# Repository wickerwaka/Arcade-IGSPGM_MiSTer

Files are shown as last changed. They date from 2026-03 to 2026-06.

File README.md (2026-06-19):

# This repository now lives in the [MiSTer organization](https://github.com/mister-devel/Arcade-IGSPGM_MiSTer)

# IGS PolyGame Master MiSTer FPGA core

The PolyGame Master (PGM) is an arcade system board released in 1997 by IGS. It has a lot of similarities to SNK's Neo Geo - cartridge based with multiple buses, heavily sprite focused graphics hardware, 68000 main CPU, Z80 for audio.

- Main processor: Motorola 68000 @ 20 MHz
- Sound processor: Zilog Z80 @ 8.4 MHz
- Sound chip: Wavefront ICS2115
- Graphics chip: IGS023

Games come with several flavors of protection hardware on the cartridge. Most feature an ARM7 CPU and in later games the ARM takes on a larger portion of the game update processing.

## Status
This core is currently BETA. Most games work, but the core needs more testing. The PGM platform features a large amount of variants and bootlegs that all require testing. If you encounter issues please report them via github. Save state files can be especially useful for tracking down and reproducing issues, so if you have some then please include them.

## Core Features
- Save States. The core supports save states for all games. It is expected that you can save and restore a save state at any point. If you encounter issues restoring save states, please report them.
- H-Scale. The PGM video signal tends to be squashed horizontally by consumer CRTs. In the Video Settings menu there is an H-Scale option that can be enabled which allows you to scale the width of the image up and down. This only works for analog video and does not play well with the HDMI scaler.
- NVRAM. The 128KB of main RAM on the PGM is battery backed. On the original system this is often used for bookkeeping data such as earning per game. Some games (CAVE shooters) use it for storing per-game settings. It might also be used for high score saving by some games.
- RTC. The PGM also has a battery backed clock. As far as I know this is not used by any games, but it does get displayed at startup by the BIOS. The timer can be adjusted in the BIOS, but at startup it will always be set to the MiSTers current system time.

## Supported games

- Oriental Legend
- Oriental Legend Super
- Dragon World 3
- Dragon World 3 EX
- Dragon World 2001
- The Killing Blade
- The Killing Blade Plus
- Photo Y2K
- Knights of Valour Super Heroes
- Knights of Valour 2
- Martial Masters
- Demon Front
- The Gladiator
- S.V.G. - Spectral vs Generation
- DoDonPachi II - Bee Storm
- DoDonPachi III / Dai-Ou-Jou
- Ketsui: Kizuna Jigoku Tachi
- Espgaluda

## Not yet working

- Knights of Valour
- Knights of Valour Plus
- Knights of Valour 2 Plus - Nine Dragons
- Dragon World Pretty Chance
- Happy 6-in-1

## Sources
Multiple different sources have been used as reference when developing this core.

[MAME](https://www.mamedev.org/) - Tons of information about the PGM system and especially its protection mechanisms. Also used as the source for the initial ICS2115 implementation.

[igspgm.com](https://igspgm.com/) - Motherboard images, cartridge images, archived documents. Super valuable archive of information that could easily have been lost to history.

[PGMTech](https://github.com/laoo/PGMTech) - Solid documentation of PGM memory maps and system architecture

[GUS GF1 Decap](https://github.com/nukeykt/LPC-GUS) - Coming from the same hardware lineage, the GF1 source was a useful reference for how things might be done inside the ICS2115

[Game Bub](https://github.com/elipsitz/gamebub) - ARM7TDMI implementation

## Special Thanks
Thanks to [James](https://www.retrohq.co.uk/) for all the additional insights he was able to provide. The stars aligned and we ended up exploring parts of the system as the same time. I hope I was able to help him half as much as he helped me.

Thanks to [Tim](https://igspgm.com/) for keeping valuable sources of PGM information alive on the internet over the years. It has been an invaluable source of information.

laoo, Xolod, augitesoul and everyone who has playtested, provided feedback and/or support.

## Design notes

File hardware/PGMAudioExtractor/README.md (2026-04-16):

# PGMAudioExtractor

PGMAudioExtractor is RP2350/Pico 2 firmware for capturing the PGM arcade board's external stereo serial audio stream at its **native sample rate** and exporting it over USB CDC as timestamped binary packets.

The host-side capture tool reconstructs the stream into:
- a `.wav` file for listening
- a `.jsonl` metadata sidecar for integrity and timing analysis

This project no longer uses USB Audio Class for primary capture. The current design is aimed at **faithful native-rate extraction** rather than presenting as a standard microphone.

## Current status

Implemented:
- PIO + DMA capture from `CLK`, `LRCLK`, and `SI`
- runtime LRCLK measurement
- native-rate CDC packet transport
- packet metadata with block sequence, frame index, timestamps, and measured LRCLK
- host-side Python capture tool
- picotool-compatible reset/load workflow
- correct capture of both silence and active audio on macOS

See [TODO.md](TODO.md) for remaining cleanup and validation work.

## Audio format assumptions

Current input assumptions:
- externally clocked serial audio
- signals: `CLK`, `LRCLK`, `SI`
- stereo
- signed 16-bit PCM
- 2's complement
- MSB first
- backward-justified / I2S-like timing
- native source rates currently observed around `33074 Hz`, with `44100 Hz` also expected

## USB interface model

The firmware currently enumerates as:
- CDC serial interface carrying the binary capture stream
- reset/vendor interface for `picotool` reboot workflows

There is no UAC streaming path in the current extractor design.

## Build

```sh
make
```

Useful targets:

```sh
make                 # build UF2
make build           # configure + build
make info            # query device info
make load            # build and flash UF2
make bootsel         # reboot device into BOOTSEL mode
make app             # reboot device into application mode
make monitor         # open a serial monitor using screen
make capture         # run Python capture tool (default /tmp/pgm_capture.wav)
make clean           # remove build directory
```

Examples:

```sh
make load
make capture
make capture OUT=/tmp/pgm.wav DURATION=20
make PORT=/dev/cu.usbmodem1101 monitor
```

Defaults can be overridden:

```sh
make PICO_BOARD=pico2
make UF2=build/pgm_audio_extractor.uf2 load
make PORT=/dev/cu.usbmodem1234561 monitor
```

## Capture workflow

Typical workflow:

```sh
make load
make capture OUT=/tmp/pgm_capture.wav DURATION=10
```

This produces:
- `/tmp/pgm_capture.wav`
- `/tmp/pgm_capture.wav.jsonl`
- `/tmp/pgm_capture.wav.raw`

The `.jsonl` file contains one JSON record per received packet with header fields and decoded status payloads.

## Packet protocol

The CDC stream is framed as binary packets with a fixed header followed by a payload.

See [PROTOCOL.md](PROTOCOL.md) for the packet layout and field definitions.

## Resilience behavior

The firmware is designed to tolerate:
- no audio source connected
- no valid LRCLK edges
- no host attached to CDC
- host attached but not actively reading

When no source is present, the device continues running and emits status packets when possible.
When the host is not connected or not draining the CDC stream, packets are dropped instead of blocking capture.

## File layout

- `CMakeLists.txt` - project build setup
- `Makefile` - build, flash, and host capture helpers
- `PROTOCOL.md` - CDC packet protocol documentation
- `src/main.c` - top-level init and main loop
- `src/tusb_config.h` - TinyUSB configuration
- `src/usb_descriptors.[ch]` - USB CDC + reset descriptors
- `src/serial_audio_capture.[ch]` - PIO/DMA capture and packet emission
- `src/serial_audio_capture.pio` - PIO program source
- `src/capture_stream.[ch]` - CDC packet queueing/transport
- `src/rate_measure.[ch]` - LRCLK measurement logic
- `src/ring_buffer.[ch]` - shared stereo frame type / helper ring buffer
- `../../utils/capture_stream.py` - host-side capture/decode tool for both hardware CDC streams and simulator binary packet captures
- `tools/serial_monitor.py` - reconnecting serial monitor helper

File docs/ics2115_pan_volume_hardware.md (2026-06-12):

# ICS2115 hardware pan/volume measurements

`pan_vol_test.csv` records one-voice output for a constant input sample of
`-32768`.  The swept fields are:

- `pan`: `0x00..0xf0` in steps of `0x10`
- `vol_acc`: `0x0000..0xfff0` in steps of `0x10`
- `left`, `right`: captured output samples

The measurements imply that the mixer computes a 12-bit volume index from
`vol_acc >> 4`, subtracts a pan attenuation from that index, converts the result
through a 4096-entry exponential volume table, and then multiplies the sample by
that table value.

## Exact measured function

This Python code reproduces every row of `pan_vol_test.csv` exactly:

```py
import csv

PAN_ATTEN = [
    4096, 508, 364, 304,
    248, 200, 168, 140,
    116, 96, 76, 56,
    40, 28, 12, 0,
]

def volume_lut(i):
    if i <= 0:
        return 0
    if i > 4095:
        i = 4095

    exp = i >> 8
    mant = i & 0xff

    if exp == 0:
        return mant >> 7

    return (((0x100 | mant) << (exp - 1)) + 0xff) >> 8

def f(sample, pan, volume):
    vol_index = volume >> 4
    pan_index = pan >> 4

    left_atten = PAN_ATTEN[15 - pan_index]
    right_atten = PAN_ATTEN[pan_index]

    left_gain = volume_lut(vol_index - left_atten)
    right_gain = volume_lut(vol_index - right_atten)

    left = (sample * left_gain) >> 15
    right = (sample * right_gain) >> 15
    return left, right

bad = []
with open('pan_vol_test.csv', newline='') as fh:
    for row in csv.DictReader(fh):
        pan = int(row['pan'])
        volume = int(row['vol_acc'])
        expected = (int(row['left']), int(row['right']))
        got = f(-32768, pan, volume)
        if got != expected:
            bad.append((pan, volume, expected, got))

print(len(bad))  # 0
```

For `sample == -32768`, the final multiply simplifies to `-gain` because:

```py
(-32768 * gain) >> 15 == -gain
```

## Volume table

The measured table is close to the old MAME/HDL patent-derived table, but it
rounds upward for non-zero fractional entries.

Measured table:

```py
def volume_lut(i):
    if i <= 0:
        return 0
    exp = i >> 8
    mant = i & 0xff
    if exp == 0:
        return mant >> 7
    return (((0x100 | mant) << (exp - 1)) + 0xff) >> 8
```

Equivalent interpretation for `exp > 0`:

```py
ceil(((0x100 | mant) << exp) / 512)
```

The `exp == 0` case must be special-cased; otherwise `exp - 1` is `-1`, which
would be an invalid negative shift in Python and undefined/impossible in C/HDL.

Examples:

```text
index  old MAME/HDL  measured
128    0             1
255    0             1
256    1             1
257    1             2
511    1             2
4095   32704         32704
```

## Pan table

The old MAME/HDL table used:

```text
panlaw[0] = 0xfff
panlaw[i] = 16 - floor(log2(i))
```

The hardware measurements instead match a 16-step attenuation table indexed by
`pan >> 4`:

```py
PAN_ATTEN = [
    4096, 508, 364, 304,
    248, 200, 168, 140,
    116, 96, 76, 56,
    40, 28, 12, 0,
]
```

The HDL stores attenuation in 12 bits, so the first entry is represented as
`0xfff`.  For the measured 12-bit volume index range, `4096` and `4095` both
fully mute because the post-pan index is `<= 0`.

Stereo uses the table symmetrically:

```py
left_atten = PAN_ATTEN[15 - (pan >> 4)]
right_atten = PAN_ATTEN[pan >> 4]
```

Only pan values in steps of `0x10` were measured in this CSV.  The HDL and MAME
now map all values with the same high nibble to the same attenuation, matching
what the measured function does for the swept values.

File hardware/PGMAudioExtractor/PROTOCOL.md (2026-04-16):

# CDC Capture Protocol

PGMAudioExtractor streams native-rate audio over USB CDC as binary packets.

All fields are little-endian.

## Packet framing

Each packet is:
- a fixed header
- followed immediately by `payload_bytes` bytes of payload

Header C definition:

```c
typedef struct __attribute__((packed)) {
    uint32_t magic;        // 'PGMA' = 0x414D4750
    uint16_t version;      // currently 1
    uint16_t type;         // 1 = audio, 2 = status
    uint32_t payload_bytes;
    uint32_t block_seq;
    uint64_t frame_start;
    uint32_t frame_count;
    uint64_t t_us;
    uint32_t raw_lrclk_hz;
    uint32_t flags;
} pgm_capture_packet_header_t;
```

## Common header fields

- `magic`: sync word used to recover framing
- `version`: protocol version
- `type`: payload type
- `payload_bytes`: number of bytes after the header
- `block_seq`: monotonically increasing packet/block sequence number
- `frame_start`: first stereo frame index represented by this packet
- `frame_count`: number of stereo frames represented by this packet
- `t_us`: `time_us_64()` timestamp captured on-device when the packet/block was emitted
- `raw_lrclk_hz`: current unsnapped measured LRCLK rate in Hz, or `0` when unavailable
- `flags`: status bitfield

## Packet types

### Type 1: audio block

Payload is raw interleaved stereo PCM frames:

```c
typedef struct {
    int16_t left;
    int16_t right;
} stereo_frame_t;
```

For audio packets:
- `payload_bytes = frame_count * 4`
- `frame_start` and `frame_count` define the exact sample range in the capture timeline

### Type 2: status

Payload C definition:

```c
typedef struct __attribute__((packed)) {
    uint32_t uptime_ms;
    uint32_t rate_hz;
    uint32_t raw_rate_hz;
    uint32_t edge_count;
    uint32_t elapsed_us;
    uint32_t idle_us;
    uint32_t rate_status;
    uint32_t ready_mask;
    uint32_t processed_dma_blocks;
    uint32_t dropped_dma_blocks;
    uint32_t dropped_audio_frames;
    uint32_t channel_word_count;
    uint32_t stereo_frame_count;
    uint32_t nonzero_sample_count;
    int16_t last_left_sample;
    int16_t last_right_sample;
    uint32_t stream_dropped_packets;
    uint32_t stream_dropped_bytes;
    uint32_t stream_queue_depth;
    uint32_t reserved;
} pgm_capture_status_payload_t;
```

Status packets provide periodic health/diagnostic information and do not contribute audio samples.

## Flags

Current flag definitions:

- `1 << 0` `PGM_CAPTURE_FLAG_RATE_VALID`
- `1 << 1` `PGM_CAPTURE_FLAG_CAPTURE_RUNNING`
- `1 << 2` `PGM_CAPTURE_FLAG_DMA_DROP`
- `1 << 3` `PGM_CAPTURE_FLAG_AUDIO_DROP`
- `1 << 4` `PGM_CAPTURE_FLAG_QUEUE_DROP`
- `1 << 5` `PGM_CAPTURE_FLAG_NO_HOST`

## Timeline model

The primary timing model is:
- sample values from audio payloads
- monotonically increasing `frame_start` / `frame_count`

`t_us` is an anchor timestamp for block emission, not a per-sample timestamp.

## Integrity checking

The host should verify:
- `block_seq` continuity
- `frame_start` continuity across audio packets
- absence of diagnostic drop flags when lossless capture is desired

The provided `utils/capture_stream.py` receiver records packet metadata to JSONL and summarizes packet/frame gaps at the end of capture. It can read either the live CDC stream from the capture hardware or a simulator-produced binary packet file.

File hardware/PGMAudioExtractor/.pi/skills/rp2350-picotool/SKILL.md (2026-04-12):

---
name: rp2350-picotool
description: "Use picotool to talk to the RP2350 device, check boot mode, query info, reboot between BOOTSEL and APPLICATION, and load UF2 firmware."
---

Use this skill whenever working with the RP2350-based device attached to this project.

## Device modes

The device has two important modes:

- `BOOTSEL` mode
  - firmware can be loaded
  - `picotool info` should work
  - `picotool load <file.uf2>` should work
- `APPLICATION` mode
  - normal firmware execution mode

## Mode switching

Reboot the device into `BOOTSEL` mode with:

```bash
picotool reboot -u -F
```

Reboot the device into `APPLICATION` mode with:

```bash
picotool reboot -a -F
```

Notes:
- `-F` forces the operation without interactive confirmation.
- The current firmware exposes the Pico USB reset interface, so `picotool reboot -u -F` should work from `APPLICATION` mode.
- After a mode switch, allow a short delay and retry once if `picotool info` or `picotool load` races device re-enumeration.
- If `picotool reboot -u -F` fails to put the device into `BOOTSEL` mode, the device may be in a bad state.
- In that case, stop and prompt the user with exactly:

```text
BOOTSEL PLZ?!
```

The user will then manually place the device into `BOOTSEL` mode.

## BOOTSEL-only commands

These commands require the device to already be in `BOOTSEL` mode and will error otherwise:

```bash
picotool info
picotool load <firmware.uf2>
```

`picotool load <firmware.uf2>` reboots the device into `APPLICATION` mode when the load completes successfully.

## Recommended workflows

### Check device status / inspect firmware

1. Try to enter `BOOTSEL` mode:

```bash
picotool reboot -u -F
```

2. Query device info:

```bash
picotool info
```

If `picotool info` fails immediately after rebooting into `BOOTSEL`, wait briefly and retry once.

3. If step 1 fails or step 2 indicates the device is not in `BOOTSEL`, ask the user:

```text
BOOTSEL PLZ?!
```

4. After the user intervenes, retry:

```bash
picotool info
```

### Load new firmware

1. Put device in `BOOTSEL` mode:

```bash
picotool reboot -u -F
```

2. Load firmware:

```bash
picotool load <path-to-firmware.uf2>
```

If `picotool load` fails immediately after entering `BOOTSEL`, wait briefly and retry once.

3. If entering `BOOTSEL` fails, ask the user exactly:

```text
BOOTSEL PLZ?!
```

Then retry the load.

## Operational guidance

- Prefer `picotool info` to confirm the device is reachable in `BOOTSEL` mode before loading firmware.
- Do not assume `picotool load` can succeed from `APPLICATION` mode.
- A successful `picotool load` returns the device to `APPLICATION` mode automatically, so no extra reboot command is needed afterward.
- If a BOOTSEL transition just occurred, allow a short re-enumeration delay before deciding the command failed.
- When reporting status, mention which mode the device is believed to be in.
- Include the exact `picotool` command used when summarizing actions.

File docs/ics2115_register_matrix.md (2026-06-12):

# ICS2115 Register Behavior Matrix

Tracking document for validating the ICS2115 RTL (`rtl/ics2115/`) against real
hardware. Every known register access from firmware evidence gets one or more
**behavior rows**; each row carries a status and a test ID. The goal is to burn
this document down until every row is `TESTED-PASS` or justified `N/A`, with a
test suite that produces identical output on the simulator and real hardware.

Evidence corpora, in order of authority:

1. **PGM Z80 BIOS** decompile — `~/Source/PGM-BIOS/pgm_bios_z80_raw_decompiled.c`
   (access sites enumerated in [`ics2115_access_inventory.csv`](ics2115_access_inventory.csv),
   regenerate/verify with `python3 util/ics_access_inventory.py [--check]`).
2. **Turtle Beach WaveFront firmware** (`OSWF.bin`) — analyzed in
   `~/Source/PGM-BIOS/ICS2115_OSCILLATOR_REGISTERS.md` (cited below as **TB doc**).
3. **Hardware experiments** — prior captures behind
   `docs/ics2115_pan_volume_hardware.md` and `docs/ics2115_vol_incr_analysis.md`.
4. **MAME** `~/Source/mame/src/devices/sound/ics2115.cpp` — reference only, has
   open TODOs ("Verify interrupt, envelope, timer period / Verify unemulated
   registers", ics2115.cpp:14-15).
5. **GF1 netlist** `~/Source/ICS2115/LPC-GUS/gf1.v` — microarchitecture hints
   from a related chip (timers ~440-487, voice RAM ~73-300); never authority.

## Status legend

```
UNKNOWN       no evidence for what real hardware does
ASSUMED       behavior inferred from firmware usage / references; not modeled or untested
MODELED       RTL implements the assumed behavior; no register-level validation test yet
TEST-DEFINED  test exists, not yet run on both targets
TESTED-SIM    test passes on simulator; hardware run pending
TESTED-PASS   sim and hardware match (and match the assumed behavior)
TESTED-FAIL   sim/hardware diverge, or hardware contradicts the assumption -> RTL fix needed
N/A           unreachable / don't-care (justification required)
```

Burn-down dashboard (run from repo root):

```bash
grep -oE '\| (UNKNOWN|ASSUMED|MODELED|TEST-DEFINED|TESTED-SIM|TESTED-PASS|TESTED-FAIL|N/A) \|' \
    docs/ics2115_register_matrix.md | sort | uniq -c
```

## Test ID index

Tests live in `util/ics_reg_tests/` (T-RB and T-PROBE implemented; runner
`util/run_ics_reg_tests.py --target {sim,hw}`, differ
`util/compare_ics_results.py`). All run through the Z80 driver path on both
targets (`ICS2115Remote` hardware / `open_sim(transport="debug_link")`),
emitting JSONL for a common differ.
**Sim-native (`SimICS2115Remote`) is introspection-only** — it bypasses the
register interface and returns zeroed IRQ counts.

Most rows are **record-only**: the test records what the chip does rather than
asserting an expectation, and adjudication happens when the hardware JSONL is
diffed against the sim baseline. For those rows `TESTED-SIM` means the sim
baseline is captured and deterministic (two consecutive runs diff clean —
verified 2026-06-11, 152/152 records, `results/sim_run1.jsonl` is the baseline
artifact).

The sim debug-link transport is validated (2026-06-11,
`audio_tests/debug_link_bench.py`): ~1 vblank frame of emulated time per
synchronous command (~0.6 s wall; `read_voice` 2 frames), 200/200 mixed
read/write ops clean. In the simulator the byte stream rides a WORK_RAM ring
(`RamComms`, see `docs/ics2115_remote.md`) because `rom_cache` makes the
PicoROM ROM-mailbox incoherent there; the TestROM auto-detects and the 68k/Z80
register path is identical on both targets. Batch requests to amortize the
per-poll frame cost in large sweeps.

| ID | What it does | Infra needed |
|---|---|---|
| T-RB | per-register readback: walking bits, voice-select isolation, byte-width disturbance (does a LOWER8 write touch the upper byte?) | existing protocol |
| T-PROBE | reserved regs 0x13-0x3F, 0x44-0x49, 0x4E: read defaults, write-then-read, full 0x40-0x4F snapshot before/after to catch aliasing, IRQ-count + audio side-effect check | existing protocol |
| T-TMR | timer period vs `((scale&0x1f)+1)*(preset+1) << (4+(scale>>5))`: (preset, scale) grid incl. 0x00/0x1f/shift extremes, measured as IRQs per N vblank frames | I-1 |
| T-IRQ | 0x4A enable-vs-pending, 0x43 read status bits, clear-on-read of 0x40/0x41 (which port widths trigger it?), IRQ line gating with enable=0 | I-1, I-2 |
| T-IRQV | multi-source IRQV ordering/priority, auto-clear granularity (one source or both? low-byte vs high-byte read?), ActiveOsc gating of the scan, idle read value | I-2 |
| T-VOICE | one-shot/loop/bidir end IRQs, vol-ramp IRQ at VEnd, IRQ from a voice above ActiveOsc | I-2 |
| T-OCTL | OscCtl key-on variants 0x10/0x20/0x30 (audio effect?), `shadow|0x02` transient, readback width/value, MAME's timer-start-bit guess (write bit0/1 with timers configured but stopped, watch IRQ counts) | I-1 |
| T-VMODE | 0x12 per-voice vs global scope (write voice A, read voice B), bits 7:2 readback + audio effect | audio capture |
| T-SYS | 0x4D readback + bit-gating side effects + strobe replay; 0x4C write sensitivity; 0x4B vector semantics; reg-select port echo; port-0 status bits | I-1, audio capture |
| T-AUD | OscConf format-bit encoding sweep (TB doc conclusion 4), regression of pan/vol tables | existing capture/compare |

Infra items: **I-1** = frame-counted IRQ measurement (TestROM vblank frame
counter + atomic `{frame_count, irq_counts}` remote command) and **I-2** =
Z80-side IRQ event ring (raw status/IRQV/0x43 bytes per service, 32 entries) —
both implemented 2026-06-11 (driver magic 0x1c52) and validated: measured
timer rate 35 IRQs/20 frames vs 34.9 predicted at 103 Hz.

**Convergence status (2026-06-12)**: after the RTL fix package, 172/178
records match between targets (`results/sim_baseline.jsonl` vs
`results/hw_baseline.jsonl`). The 6 residuals: hardware run-to-run variance
in IRQV round-robin corner cases (multi-pend ordering and ActiveOsc gating
need tests that precondition the round-robin pointer deterministically),
the 0x4D initial-read bit3 quirk, VCtl/OscConf 0xFF-pattern readback
variance (engine-state-dependent), and the latched-delivery stat43 nuance.
PGM BIOS boots in sim with audio on the new RTL.

Timer measurement constraints (measured in sim): timer rates above ~2 kHz
IRQ-storm the Z80 and starve its command loop entirely; above ~830 Hz the
Z80 service loop saturates and counts read exactly half (fires merge into the
still-set pending bit). The ceiling differs between targets (ICS port wait
states), so T-TMR grid points stay <= ~420 Hz. T-TMR/T-IRQ/T-IRQV sim
baseline: `results/sim_irq_run2.jsonl` (determinism verified 20/20 vs run3).

---

# Hardware findings — global conventions (2026-06-11, first hardware sessions)

Cross-cutting discoveries from the first real-hardware suite run and the
follow-up characterization sessions (full per-register details in the
sections below; raw data `results/hw_run1.jsonl` + session transcripts):

- **Unimplemented bits and byte lanes read as 1** (pulled high), not 0:
  unused low lanes of Upper8 registers read 0xFF; pan low nibble, VMode upper
  nibble, OscAcc-low bits 2:0, OscFC bit 0 all read as ones. The RTL/MAME
  convention of returning 0 for unimplemented bits is wrong almost
  everywhere. Exception: OscSAddr's other lane reads 0x3F (bits 7:6 driven
  low — saddr may be wider than 8 bits).
- **Several registers store fewer bits than modeled**: pan = 4 bits (upper
  nibble; matches the 16-step pan table), VMode = 4 bits (rate[1:0] +
  phase[3:2], per-voice), OscCtl = 2 bits (RTL already correct).
- **Timer architecture is asymmetric** (see 0x42/0x43): timer 0 = mult+shift
  from 0x42; timer 1 = shift-only from 0x43[7:5]; IRQ output enables are
  0x43 bits 3 (t0) and 4 (t1); 0x4A is uninvolved; 0x4D bit 0 gates timer
  counting entirely.
- **Voice IRQ model (T-VOICE, real oscillator events)**: per-voice enable =
  OscConf bit5 (osc) / VCtl bit5 (vol); global output gate = **0x4A** (with
  0x4A=0 the pend latches silently; with 1 the Z80 is interrupted). The INT
  level follows (source condition AND enables) — clearing conf bit7 alone
  re-asserts immediately (measured 12k storm services); the ack is clearing
  the per-voice enable / tearing the voice down, exactly what the BIOS
  handler does. IRQV is NOT clear-on-read. 0x4B reads 0x80|voice while an
  osc IRQ pends, and its voice field even tracks non-pending end events
  (valid bit clear). Earlier "host pends never assert" observations were
  made with 0x4A=0.
- **IRQV idle value retains the last reported voice** in bits 4:0 (e.g. 0xE2
  after voice 2), unlike the RTL's 0xFF; the latch even survives a board
  reset (ICS state is not cleared by the 68k reset line).
- **Register selects 0x50-0x57 hit real registers** (distinct lane-structured
  values: 0x7474, 0x4d4d, 0x7d7d, 0x8888, 0x20a0, 0x5050); 0x58+ reads
  constant 0x7878 (open bus). Unprobed beyond reads.
- **Hardware Z80 IRQ service ceiling is >1033 Hz** (vs ~830 Hz in the
  simulator) — T-TMR grid points stay <= ~420 Hz to be exact on both.
- The suspected "stale-read wedge" in the first hardware runs was NOT a
  wedge: every reading is explained by (a) timers unarmed without the 0x43
  enable bits, and (b) host voice-pends requiring OscConf bit7 AND bit5
  together (0x80 alone latches nothing, so IRQV/0x4B/conf reads showed
  idle values). Full-sequence bisects with canaries confirm the read paths
  are robust. The one REAL hazard: writes to reserved voice registers —
  0xFFFF to 0x13 hung the ICS host interface (BUSY stuck) in one session,
  state-dependent; write probing now lives in the separate t_probe_w group,
  excluded from hardware baselines.
- Timer-0 mult field 0 (scale[4:0]=0) stops timer 0 entirely on hardware,
  like preset=0.

# Direct host ports (Z80 0x8000-0x8003)

These are not indexed registers but the four bus ports; the BIOS proves
behaviors here that predate any register access.

## Port 0x8000 — status (read)

RTL: `ics2115.sv:735-754`. bit7 = any enabled IRQ active, bit1 = any voice IRQ
pending, bit0 = timer IRQ pending&enabled, bit6 = **RTL-specific** "buffered
voice write FIFO busy".

Evidence: PGM drivers dispatch on bit1 -> IRQV drain loop (comment at
`ics2115.sv:687-690`); BIOS helper `ReadIrqStatusPort` (ram:02a3) exists but has
**no caller in the decompiled BIOS** — the dispatch evidence comes from game
drivers (theglad/espgaluda).

| ID | Assumed behavior | Test | Status |
|---|---|---|---|
| P0-A | bit7 = master IRQ flag, bit1 = voice IRQ, bit0 = timer IRQ | T-SYS | MODELED |
| P0-B | bit1 polarity/gating: raw pending vs enable-gated (RTL gates the whole byte under `irq_on` but bit1 itself is raw pending) | T-IRQ | ASSUMED |
| P0-C | bit6 read value on real hardware (RTL uses it for its write-FIFO; real chip may define it differently or not at all) | T-SYS | UNKNOWN |

## Port 0x8001 — register select (write + **readback**)

RTL: echo modeled at `ics2115.sv:749`.

Evidence: `ProbeSoundChipRevision` (ram:16f2) writes 0x5a, 0xa5, 0x4c to this
port and **reads each back expecting the written value** before reading the
revision from the data port. Chip presence detection depends on this echo.

| ID | Assumed behavior | Test | Status |
|---|---|---|---|
| P1-A | reading port 1 returns the last written register index, for arbitrary values incl. non-existent registers (0x5a, 0xa5) | T-SYS | MODELED |

## Ports 0x8002/0x8003 — data low / data high

RTL: `ics2115.sv:750-751` (read), write decode `ics2115.sv:~1104-1180`.
Conventions (CLAUDE.md, confirmed by BIOS): word writes are low byte then high
byte; regs 0x06/0x07/0x08/0x12 are Upper8 accesses; 0x0e/0x0f are global —
never precede with a voice select.

| ID | Assumed behavior | Test | Status |
|---|---|---|---|
| P2-A | low-then-high write ordering forms a 16-bit write; what does a high-only or low-only write do to the other byte per register? | T-RB | TESTED-PASS |
| P2-B | read side-effects (IRQV clear, timer IRQ clear) trigger on the correct port: RTL clears IRQV only on **high-byte** read (`ics2115.sv:707`), timer IRQ on **either** byte (`ics2115.sv:727`) | T-IRQ, T-IRQV | ASSUMED |

---

# Per-voice registers (0x00-0x12, selected via 0x4F)

RTL read mux `ics2115.sv:570-655`; voice writes are buffered through a FIFO
(`ics2115.sv:~1104-1145`) and applied by `apply_voice_reg_byte`
(`ics2115.sv:758+`); envelope/oscillator engine in `ics2115_osc.sv`.

## 0x00 — OscConf (oscillator configuration) — Upper8

Bits (TB doc + PGM, corroborating): 7=IRQ pending/status, 6=invert/reverse,
5=IRQ enable, 4=bidir, 3=loop, 1:0=sample format. **Format encoding (TB doc
conclusion 4): `00`=linear 8-bit, `01`=u-law 8-bit, `10`=linear 16-bit,
`11`=white noise/special — diverges from MAME's bit2=8bit/bit1=stop model.**

Evidence: 6 BIOS sites (inventory). Key ones: `InitializeSoundChannels` writes
0x00 after key-off; init self-test polls OscConf until bit7 clears
(ram:17a6 loop), then forces `OscConf=0xa0` (pending+enable) to provoke the
0x4B vector check; IRQ handler reads it during voice teardown (L1330). PGM sets
bit5 for one-shot completion IRQs (TB doc conclusion 7).

RTL: read `ics2115.sv:573-575`; flags decoded per the firmware model
(`OSC_IRQ_PEND(7), INVERT(6), IRQ_EN(5), BIDIR(4), LOOP(3), 16BIT(1), ULAW(0)`);
osc-end IRQ sets bit7 in `ics2115_osc.sv:479-482`.

| ID | Assumed behavior | Test | Status |
|---|---|---|---|
| 00-A | readback returns written value; bit7 set by hardware on osc IRQ | T-RB, T-VOICE | TESTED-SIM |
| 00-B | format bits 1:0 per TB encoding incl. `11` = white noise/special | T-AUD | TESTED-PASS |
| 00-C | hardware: host pend requires bit7 AND bit5 together (0xA0); bit7 alone is a no-op (RTL pends on bit7 alone). Pend populates 0x4B (0x80|voice) and IRQV but never asserts the IRQ output | T-IRQV | TESTED-PASS |
| 00-D | bit5=0 with pending bit7=1: is the IRQ line masked but the bit retained? | T-VOICE | TESTED-PASS |

## 0x01 — OscFC (frequency counter) — WORD

Evidence: 2 BIOS sites, always `WriteICSRegisterWord(1, ...)` from pitch tables.
RTL: `ics2115.sv:578` read; low-byte write forces bit0=0 (`ics2115.sv:~791`),
step uses fc[15:1].

| ID | Assumed behavior | Test | Status |
|---|---|---|---|
| 01-A | 16-bit r/w; bit0 ignored/forced 0 (hardware-trace confirmed per docs/ics2115_z80_trace_compare.md) | T-RB | TESTED-PASS |

## 0x02/0x03 — OscStart high/low; 0x04/0x05 — OscEnd high/low

Evidence: 1 BIOS site each (`ProgramSoundChannelRegisters`, WORD writes).
RTL: reads `ics2115.sv:581-590` — note **low-register reads return the low
8 bits in the high byte with 0x00 low** (`{start[12:5], 8'h00}`), and low-reg
low-byte writes are ignored.

| ID | Assumed behavior | Test | Status |
|---|---|---|---|
| 02-A | 20.9 fixed-point address split across reg pairs; readback layout as modeled (incl. the `xx00` low-reg read shape) | T-RB | TESTED-PASS |
| 02-B | bits [4:0] of the low registers: RTL models them as nonexistent (write ignored, read 0) — hardware may store more precision | T-RB | TESTED-PASS |

## 0x06 — VolIncr — Upper8

Evidence: **never written by the PGM BIOS** (inventory: zero 0x06 rows — the
BIOS uses fixed VStart/VEnd=1 instead); Turtle Beach writes it during ramp
programming paired with 0x12 (TB doc). Hardware sweep already done:
`docs/ics2115_vol_incr_analysis.md` derived the rate families from real
captures (`vol_incr.csv`).

RTL: read `ics2115.sv:593`; rate families implemented in
`ics2115_osc.sv:113-149` (`calc_vol_step`).

| ID | Assumed behavior | Test | Status |
|---|---|---|---|
| 06-A | ramp rate families per vol_incr value x vmode[1:0] (measured on hardware) | T-AUD regression | TESTED-PASS |
| 06-B | readback returns written value (Upper8) | T-RB | TESTED-PASS |

## 0x07 — VolStart, 0x08 — VolEnd — Upper8

Evidence: BIOS writes both = 1 during voice init (L853-854). Hardware trace
compare confirmed these are **high-byte** accesses (docs/ics2115_z80_trace_compare.md).
RTL: read `ics2115.sv:596-599`; write sets bits 25:18, clears 17:0.

| ID | Assumed behavior | Test | Status |
|---|---|---|---|
| 07-A | Upper8 write maps to envelope bits 25:18; low bits cleared on write | T-RB | TESTED-PASS |
| 07-B | readback shape (RTL returns `{bits25:18, 8'h00}`) | T-RB | TESTED-PASS |

## 0x09 — VolAcc (volume accumulator) — WORD

Evidence: 2 BIOS sites — **both write 0x09 with values from
`z80_wave_frequency_table`** (L950, L1044; the table name is the decompiler's,
indexed by a per-note byte — this is the BIOS's volume law, not a frequency).
Hardware pan/vol sweep (`vol_pan.csv`, `docs/ics2115_pan_volume_hardware.md`)
mapped vol_acc -> amplitude exactly (exponential with ceil rounding,
`ics2115_tables.sv:34-39`).

RTL: read `ics2115.sv:602` (bits 25:10); low-byte write zeroes bits 9:0.

| ID | Assumed behavior | Test | Status |
|---|---|---|---|
| 09-A | vol_acc -> output amplitude curve (measured on hardware) | T-AUD regression | TESTED-PASS |
| 09-B | 16-bit readback of bits 25:10; write low byte clears 9:0 | T-RB | TESTED-PASS |

## 0x0A/0x0B — OscAcc high/low — WORD

Evidence: WORD writes in voice programming (L929-937); Turtle Beach manually
sets/increments these for the accumulator-monitor readback path (TB doc,
`StartAccumulatorMonitorRead`/`ReadAccumulatorMonitorByte`).
RTL: reads `ics2115.sv:605-610` (0x0B returns `{acc[12:0],3'b000}`, MAME-shape
mask 0xFFF8); 0x0B low-byte write takes data[7:3] -> acc[4:0].

| ID | Assumed behavior | Test | Status |
|---|---|---|---|
| 0A-A | r/w current sample position; readback while running returns advancing values | T-RB | MODELED |
| 0A-B | bottom-3-bit truncation shape on 0x0B read/write | T-RB | TESTED-PASS |

## 0x0C — Pan — Upper8

Evidence: 1 BIOS site (`z80_voice_pan_table` lookup). Hardware sweep mapped the
16-step pan attenuation table exactly (`docs/ics2115_pan_volume_hardware.md`,
table in `ics2115_tables.sv:53-72`).

| ID | Assumed behavior | Test | Status |
|---|---|---|---|
| 0C-A | pan -> L/R attenuation per measured 16-step table (`pan >> 4` index) | T-AUD regression | TESTED-PASS |
| 0C-B | readback returns written value | T-RB | TESTED-PASS |

## 0x0D — VCtl (volume envelope control) — Upper8

Bits (TB doc): 7=IRQ pending, 6=invert, 5=IRQ enable, 4=bidir, 3=loop,
2=rollover, 1=stop, 0=done.

Evidence: 6 BIOS sites. `InitializeSoundChannels`: read 0x0D, write back
(transient), poll until done after `OscCtl=0x0f` key-off, then write 0x03
(done+stop) before key-on setup; IRQ handler reads 0x0D and tests **bit 3**
(L1307: `& 8`) to decide voice teardown. Known hardware quirk: writing 0x00
reads back 0x01 — envelope idles in DONE (docs/ics2115_z80_trace_compare.md).

RTL: read is an **explicit stub** (`ics2115.sv:615-621`, "stub for T02 IRQ
work"): returns 0x81/0x01 depending on vmode[1:0] and the IRQ-enable flag —
it does NOT return the stored vol_ctrl bits (no bit3/loop, no real bit1/0
state). Write `ics2115.sv:~796` stores all 8 bits; vol-end IRQ sets bit7
(`ics2115_osc.sv:535-538`).

| ID | Assumed behavior | Test | Status |
|---|---|---|---|
| 0D-A | readback reflects stored control bits + live done/IRQ state (BIOS polls done; IRQ handler branches on bit3 -> the stub loses loop state the BIOS reads; **RTL stub known-divergent**) | T-RB | TESTED-SIM |
| 0D-B | write 0x00 -> reads back 0x01 (DONE set when idle; hardware-trace confirmed) | T-RB | TESTED-PASS |
| 0D-C | bit7 set by hardware at ramp end when bit5 enabled | T-VOICE | MODELED |

## 0x0E — ActiveOsc — Upper8, global

Evidence: BIOS writes 0x1f twice during init (L1551, L1614); never reduced.
MAME: sample rate = `clock / ((active+1)*32)` with "(Guessing)" on the 5-bit
mask (ics2115.cpp:150-152). PGM always runs all 32 voices, so the rate change
is **untested territory on PGM hardware**.

RTL: read `ics2115.sv:624`; write is global (not FIFO'd).

| ID | Assumed behavior | Test | Status |
|---|---|---|---|
| 0E-A | sets highest active voice; output sample rate = clock/((n+1)*32) | T-TMR (measure sample rate via timer ratio) / T-AUD | ASSUMED |
| 0E-B | gates the IRQV scan (RTL only scans voices <= active_osc) — does a pending IRQ on a voice above ActiveOsc ever surface? | T-VOICE | TESTED-SIM |
| 0E-C | readback returns 5-bit value | T-RB | TESTED-PASS |

## 0x0F — IRQV (interrupt vector) — Upper8, global, read-only

Evidence: 3 BIOS reads, all `ReadICSRegisterHigh(0xf)`. The IRQ drain loop
(`HandleIrqBit1Service`, ram:153b) reads IRQV repeatedly: voice = `v & 0x1f`,
sources = `v & 0xc0` **active-low** (bit7 clear = osc IRQ, bit6 clear = vol
IRQ), terminates when `(v & 0xc0) == 0xc0` (nothing pending). Init reads it to
flush state.

RTL: scan `ics2115.sv:628-643` — first pending voice with index <= active_osc,
idle value 0xFF; auto-clear at `ics2115.sv:696-719` triggers on **high-byte
read only** and clears **both** pending sources of the matched voice.

| ID | Assumed behavior | Test | Status |
|---|---|---|---|
| 0F-A | active-low source bits + 5-bit voice; idle read = bits 7:6 set (RTL: 0xFF — are bits 4:0 all-ones on hardware too?) | T-IRQV | TESTED-SIM |
| 0F-B | reading clears the reported voice's pending state — but which? RTL clears both osc+vol at once; hardware may clear only the reported source, or clear on low-byte reads too | T-IRQV | TESTED-SIM |
| 0F-C | scan order/priority with multiple pending voices (RTL: lowest index first) | T-IRQV | TESTED-SIM |
| 0F-D | scan gated by ActiveOsc | T-IRQV | TESTED-SIM |

## 0x10 — OscCtl — Upper8

Evidence: BIOS writes only 0x0f (key-off/reset) and 0x00 (key-on) — 2 sites.
Turtle Beach (TB doc): also writes valid key-on values **0x10/0x20/0x30**
(copied from `wavefront_patch.filterconfig` bits 5:4), transient
`shadow|0x02` while reprogramming a live voice, 0x01 during accumulator-monitor
setup, and **reads** OscCtl treating bit0 = stopped/done. MAME comment
(ics2115.cpp:843): `[7 R | 6 M2 | 5 M1 | 4-2 Reserve | 1 - Timer 2 Strt | 0 -
Timer 1 Strt]` — unimplemented guess that bits 0/1 start the timers.

RTL: read `ics2115.sv:646` returns `{6'b111111, osc_ctl[1:0]}` (upper 6 bits
forced 1); write stores 8 bits, sequencer keys on/off from 0x00/0x0f.

| ID | Assumed behavior | Test | Status |
|---|---|---|---|
| 10-A | 0x00 = key-on, 0x0f = key-off/reset | T-RB, T-AUD | MODELED |
| 10-B | 0x10/0x20/0x30 are valid key-on commands (TB) — what do bits 5:4 do audibly? | T-OCTL | UNKNOWN |
| 10-C | bit1 as temporary "reprogram gate" (TB `shadow|0x02`): voice halts cleanly and resumes | T-OCTL | UNKNOWN |
| 10-D | readback: bit0 = stopped/done status (TB reads it); RTL returns stored bits 1:0 with upper bits 1 — is the upper-6 forced-1 shape right? | T-RB, T-OCTL | TESTED-PASS |
| 10-E | MAME timer-start guess for bits 0/1: configure timers, write OscCtl bit0/1, observe timer IRQs | T-OCTL | UNKNOWN |

## 0x11 — OscSAddr (static address / bank) — Upper8

Evidence: 1 BIOS site (wave-table bank byte). RTL: read `ics2115.sv:649`,
provides ROM address bits 27:20.

| ID | Assumed behavior | Test | Status |
|---|---|---|---|
| 11-A | bank bits 27:20 of sample ROM address; readback | T-RB | TESTED-PASS |

## 0x12 — VMode — Upper8, **per-voice** (scope disputed)

Evidence: **never accessed by the PGM BIOS** (inventory). Turtle Beach writes
it per-voice during ramp programming, paired with VolIncr (TB doc, "Major
divergence" section ~L1095). MAME treats it as global `m_vmode` with comment
"Unknown variable, seems to be affected by 0x12. Further investigation
Required." (ics2115.h:156-158). Hardware vol_incr sweep showed only bits 1:0
select the rate family; bits 3:2 phase-shift but same period
(docs/ics2115_vol_incr_analysis.md).

RTL: per-voice storage, read `ics2115.sv:652`, only bits 1:0 used by
`calc_vol_step`.

| ID | Assumed behavior | Test | Status |
|---|---|---|---|
| 12-A | per-voice register (not global): write voice A, read voice B differs | T-VMODE | TESTED-PASS |
| 12-B | bits 1:0 select ramp-rate family (hardware-measured) | T-AUD regression | TESTED-PASS |
| 12-C | bits 7:2 readback + effect (3:2 phase observation needs re-test) | T-VMODE | TESTED-PASS |

---

# Reserved per-voice range

## 0x13 / 0x14 — written by Turtle Beach, otherwise reserved

Evidence: TB `ResetIcs2115VoiceRegisters` writes 0xffff to both at voice reset;
**no reads observed** (TB doc searched; only reset-time writes). PGM never
touches them. Datasheet: reserved/do-not-access.
RTL: undecoded — write dropped, read returns 0x0000 (`ics2115.sv:654` default).

| ID | Assumed behavior | Test | Status |
|---|---|---|---|
| 13-A | harmless write-only reserved regs vs. undocumented per-voice state needed for clean reset | T-PROBE | TESTED-PASS |

## 0x15-0x3F — reserved

No usage in any corpus. RTL: 0x15-0x1F hit the voice-case default (read 0);
0x20-0x3F fall to the global-case default (read 0).

| ID | Assumed behavior | Test | Status |
|---|---|---|---|
| 15-A | read default + write inertness + no aliasing onto real registers | T-PROBE | TESTED-PASS |

---

# Global registers (0x40-0x4F)

RTL read `ics2115.sv:657-675`, write `ics2115.sv:~1146-1180` (decoded:
0x40-0x43, 0x4A, 0x4F only).

## 0x40 / 0x41 — Timer 0 / Timer 1 preset — Lower8

Evidence: timer config writes (`ConfigureSoundChipVoiceMode`, ram:12bb); the
**timer IRQ service reads the fired timer's preset register to acknowledge**
(`HandleIrqBit0Service`, ram:1519: read 0x43, then read 0x40 if bit0 else
0x41 — return value discarded).

RTL: read returns preset (`ics2115.sv:659-660`); read of either byte clears
that timer's pending IRQ (`ics2115.sv:721-733`); write 0 stops the timer.

| ID | Assumed behavior | Test | Status |
|---|---|---|---|
| 40-A | write sets preset; period = `((scale&0x1f)+1)*(preset+1) << (4+(scale>>5))` (MAME formula, ics2115.cpp:1097-1101) | T-TMR | TESTED-PASS |
| 40-B | hardware: only a full 16-bit read of the preset acks; lo8/hi8 reads do NOT clear (RTL clears on either byte) | T-IRQ | TESTED-PASS |
| 40-C | read value: preset, or live countdown? (BIOS discards it; RTL returns preset) | T-RB, T-IRQ | TESTED-PASS |
| 40-D | preset=0 stops the timer (confirmed both targets) | T-TMR | TESTED-PASS |
| 40-E | hardware: timer-0 scale[4:0]=0 (mult field 0) also stops the timer — no pending, no IRQs (RTL runs at mult=1) | T-TMR | TESTED-PASS |

## 0x42 — Timer 0 scale — Lower8

Evidence: written during timer config (1 site); never read by BIOS.
RTL: write decoded; **read undecoded -> 0x00**.

| ID | Assumed behavior | Test | Status |
|---|---|---|---|
| 42-A | scale bits [4:0] multiplier, [7:5] shift | T-TMR | TESTED-PASS |
| 42-B | read value on hardware (RTL returns 0) | T-RB | TESTED-PASS |

## 0x43 — Timer control + timer-1 shift (write) / timer IRQ status (read) — Lower8

**HARDWARE-CHARACTERIZED 2026-06-11** (direct experiments, fresh-boot
sessions): the write side is a **timer control register**, not "timer 1
scale":

```
write 0x43:  bit 7:5 = timer-1 shift   (period1 = (preset1+1) << (4+shift))
             bit 4   = timer-1 IRQ output enable
             bit 3   = timer-0 IRQ output enable
             bit 2:0 = no observed rate/delivery effect
read  0x43:  bit 0/1 = timer-0/1 IRQ pending (as modeled)
```

Timer 1 has **no multiplier field** (0xF0/0xF7/0xFF all measure 65.1 Hz with
preset 255) — the timers are asymmetric: timer 0 takes mult+shift from 0x42,
timer 1 takes shift-only from 0x43[7:5]. Measured: 0x43=0xF0 -> 65.1 Hz,
0x43=0x70 -> 1033.3 Hz (shift formula exact); timer 0 with 0x43=0x08 ->
103.1 Hz (full 0x42 formula exact). **Without the 0x43 enable bit the timer
pends (read bit set) but the chip never asserts its IRQ output** — this is
why the first hardware suite run counted zero timer IRQs. The BIOS
ConfigureSoundChipVoiceMode compose `(x*0x20)|(y&0x1f)|0x10` / `|8` now reads
exactly as {shift, enables}.

RTL (now known-wrong): read returns `{6'd0, irq_pending[1:0]}`
(`ics2115.sv:663`) ✓; write sets timer-1 scale ✗ (no enable bits, mult+shift
formula for timer 1).

| ID | Assumed behavior | Test | Status |
|---|---|---|---|
| 43-A | read bit0/bit1 = timer0/timer1 IRQ pending | T-IRQ | TESTED-PASS |
| 43-B | write = timer control: t1 shift [7:5], t1 enable bit4, t0 enable bit3; t1 has no mult | T-TMR | TESTED-PASS |
| 43-C | reading 0x43 does not ack (confirmed both targets) | T-IRQ | TESTED-PASS |
| 43-D | upper 6 read bits on hardware | T-RB | TESTED-PASS |

## 0x44-0x49 — DMA / accumulator monitor

Evidence: PGM BIOS never touches them (inventory + TB doc explicitly searched
the PGM Z80 driver). Turtle Beach uses **0x48/0x49 as accumulator-monitor data
registers** to read sample memory back through voice 0
(`StartAccumulatorMonitorRead`/`ReadAccumulatorMonitorByte`, TB doc ~L728-758).
MAME: unhandled.
RTL: undecoded (read 0, write dropped).

| ID | Assumed behavior | Test | Status |
|---|---|---|---|
| 48-A | 0x48/0x49 read bytes of sample memory addressed by voice-0 OscAcc (TB usage) | T-PROBE (extended: program voice 0 acc, read 0x48/0x49) | TESTED-PASS |
| 44-A | 0x44-0x47 defaults/side effects | T-PROBE | TESTED-PASS |

## 0x4A — NOT the IRQ enable — Lower8

Evidence: single BIOS write `0x4A = 1` at end of init; never read by BIOS.
**HARDWARE 2026-06-11: 0x4A is not in the timer-IRQ path at all** — timer 0
fires identically with 0x4A=0x00 or 0x01 (enable is 0x43 bit3), and writes of
0x00/0x03/0xFF all read back constant 0x02. Function unknown; the BIOS's
`0x4A=1` may target something else entirely.
RTL (known-wrong): write sets `irq_enabled` gating the IRQ line; read returns
`irq_pending` (`ics2115.sv:666`, mirrors MAME).

| ID | Assumed behavior | Test | Status |
|---|---|---|---|
| 4A-A | hardware: 0x4A is the VOICE-IRQ output gate (oneshot delivers with 1, latches silently with 0); timers unaffected | T-VOICE | TESTED-PASS |
| 4A-B | hardware read = constant 0x02 (not pending, not enable) | T-RB | TESTED-PASS |
| 4A-C | pending latches regardless of 0x4A; IRQ line gated by 0x43 enables instead | T-IRQ | TESTED-PASS |

## 0x4B — oscillator IRQ vector? — Lower8, read-only

Evidence: BIOS init self-test (ram:17a6): select voice 0, write
`OscConf = 0xa0` (IRQ pending+enable), poll 0x4B until `(value & 0x9f) ==
0x80`, up to 255 attempts -> sound-chip error code 2 on timeout. Mask keeps
bit7 + bits 4:0 -> expects bit7 **set** and voice bits = 0. So 0x4B reads like
an osc-IRQ vector with **active-high** valid bit + voice index — opposite
polarity to IRQV(0x0F). GF1 heritage: IRQ-source register returning the
interrupting voice.

RTL: stub, always returns 0x80 (`ics2115.sv:668-669`) — passes the BIOS
self-test **only because the BIOS tests voice 0**.

**HARDWARE 2026-06-11**: idle reads 0x02 (not 0x80); with a host-pended osc
IRQ on voice 0 it reads 0x80 on the **first** poll (BIOS self-test replay
succeeded in 1 iteration). The RTL constant-0x80 stub is wrong at idle and
untested for voice != 0.

| ID | Assumed behavior | Test | Status |
|---|---|---|---|
| 4B-A | returns `0x80 | voice` while an osc IRQ pends (hw confirmed voice 0; voice != 0 still to record) | T-SYS | TESTED-PASS |
| 4B-B | idle value = 0x02 on hardware (RTL stub reads 0x80) | T-RB | TESTED-PASS |
| 4B-C | bits 6:5 meaning (masked out by BIOS) | T-SYS | UNKNOWN |

## 0x4C — chip revision — Lower8

Evidence: BIOS **writes** `0x4C = 3` during init (ram:16a0) before voice init;
revision is read via the port-echo probe sequence and must equal 1
(`VerifySoundChipOrDisplayError` hangs forever otherwise).
RTL: read-only constant 0x01 (`ics2115.sv:672`); write dropped.

| ID | Assumed behavior | Test | Status |
|---|---|---|---|
| 4C-A | reads 0x01 on PGM's chip | T-RB | TESTED-PASS |
| 4C-B | write-insensitive readback confirmed on both targets (side effects of the BIOS write-3 still unknown) | T-SYS | TESTED-PASS |

## 0x4D — system control — Lower8

Evidence (all BIOS, richest unknown register — 8 sites):
- `ResetSoundChipMixerState` (ram:173b): write 0x00, **16 dummy reads of 0x4D**
  (settle delay), write 0x01 -> bit0 looks like run/~reset.
- `InitializeSoundChipVoicesAndTables` entry (ram:17a6): RMW `& 0xf7` (clear
  bit3) before voice init; at exit writes `0x4D = 0x00` (the operand is the
  high byte of the caller's literal argument 0x004c, i.e. zero — resolved
  question G-03).
- `InitializeSoundChipCore` (ram:16a0): after voice init, RMW `| 0x0c` (set
  bits 3:2), then enables IRQs (0x4A=1).
- Net post-init state: 0x4D = 0x0c (bits 3:2 set, bit0 **clear**).

MAME: unhandled. RTL: **undecoded** — writes dropped, reads return 0.

**HARDWARE 2026-06-11**: stored/readable bit mask = **0x05** (walking writes:
only bits 0 and 2 read back; 0xFF reads 0x05). Bit 3 read as set in the boot
state (0x0D) but does not store from writes — status-ish. **Bit 0 gates the
timers**: with bit0 clear, timer pending never latches (0x43 reads 0); with
bit0 set, pending latches. Voice-register access works regardless of 0x4D.
The driver/BIOS boot state is 0x0D. Walking all bit values does NOT wedge the
register interface.

| ID | Assumed behavior | Test | Status |
|---|---|---|---|
| 4D-A | readback: stored mask 0x05 only (RTL stores nothing) | T-RB | TESTED-PASS |
| 4D-B | bit0 gates timer counting (pending never latches when clear); BIOS strobe = stop/start | T-IRQ | TESTED-PASS |
| 4D-C | bit2 stored (function unknown); bit3 status-ish, not stored; audio effects untested | T-SYS | ASSUMED |
| 4D-D | RTL must model: stored mask 0x05, bit0 timer gate | — | TESTED-PASS |

## 0x4E — unused

No usage in any corpus. RTL: undecoded.

| ID | Assumed behavior | Test | Status |
|---|---|---|---|
| 4E-A | default read / write inertness | T-PROBE | TESTED-PASS |

## 0x4F — oscillator select — Lower8, write-only(?)

Evidence: 7 BIOS sites via `WriteICSSelectOscillator`; never read.
RTL: write sets `osc_select` (`ics2115.sv:~1170`); read undecoded -> 0.

| ID | Assumed behavior | Test | Status |
|---|---|---|---|
| 4F-A | selects voice for indexed regs 0x00-0x12 | T-RB (isolation: write voice A's reg, verify voice B unchanged) | TESTED-PASS |
| 4F-B | hardware: readable, returns the selected voice (0x00/0x07/0x1f echo back; RTL reads 0) | T-RB | TESTED-PASS |
| 4F-C | values > 0x1f: masked to 5 bits? | T-PROBE | UNKNOWN |

---

# Resolved static-analysis questions (G-tasks)

| ID | Question | Resolution |
|---|---|---|
| G-01 | Turtle Beach OscCtl 0x10/0x20/0x30 origin + readback | From `wavefront_patch` byte+6 bits 5:4 (`filterconfig`), copied at key-on (`StartMidiVoiceForSample`); OscCtl **is** read back, bit0 treated as stopped/done (TB doc L146-165, 298-311). Hardware meaning of bits 5:4 -> T-OCTL. |
| G-02 | 0x13/0x14 ever read? | No — only reset-time 0xffff writes (TB doc searched). Re-verify needs `turtle_beach.gpr` opened in Ghidra (the OSWF.bin copy in the running ketbl project is unanalyzed). |
| G-03 | Value written to 0x4D at decompile L1621 | `(0x004c >> 8) = 0x00` — the decompiler reused the caller's literal argument slot. Sequence fully reconstructed under 0x4D above. |
| G-04 | 0x4B poll loop semantics | Init self-test: force `OscConf=0xa0` on voice 0, poll 0x4B for `(v&0x9f)==0x80`, error code 2 on 255-try timeout. Implies active-high osc-IRQ vector; RTL stub passes by coincidence. |
| G-05 | DYNAMIC register indices in inventory | None — all 61 BIOS call sites use literal register numbers (only some *values* are dynamic, all table-driven voice parameters). |

# Known coverage gaps

- **Game Z80 drivers** (theglad, espgaluda, kov2 etc.) are not in the text
  inventory — only Ghidra projects exist. TB doc conclusion 8 covers
  espgaluda's conservative OscCtl usage; a fuller audit can extend
  `util/ics_access_inventory.py` once decompile text exports exist.
- **`ReadIrqStatusPort` has no decompiled caller** — the BIOS IRQ entry is
  likely asm-level (vector at ram:0038?); the port-0 dispatch evidence comes
  from game drivers. Worth confirming the BIOS IRQ entry path in Ghidra.
- Timer absolute clock base: T-TMR measures against vblank; the sim/hw vblank
  rates are the same RTL, but the chip input clock divisor itself is taken
  from MAME and untested.

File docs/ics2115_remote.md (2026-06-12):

# ICS2115 remote hardware control

This is an interactive hardware test path for changing ICS2115 registers through PicoROM/debug-link and sampling audio through the PGMAudioExtractor/capture stream.

## TestROM page

Build and upload the new page:

```sh
make -j8 -C testroms TARGET=pgm_test PAGE=ics_remote
make -C testroms TARGET=pgm_test PAGE=ics_remote picorom
```

The page uses `testroms/debug_link.h` and forwards commands to the existing Z80 ICS driver through `z80_ics_host.c`.

## Python library

Main control API:

```py
from util.ics2115_remote import ICS2115Remote, Voice

with ICS2115Remote.open('pgm') as ics:
    print(ics.ping())

    # Register access by datasheet-ish or struct field names.
    # VMode is per-voice register 0x12 and uses the upper data port.
    ics.write_global('ACTIVE_OSC', 0x1f)
    ics.write_reg(0, 'OSC_FC', 0x0155)
    ics.write_reg(0, 'VMode', 0x00)
    print(hex(ics.read_reg(0, 'osc_fc')))

    # Full voice access with raw fields plus friendly address helpers.
    v = Voice.from_bios_trace()
    ics.write_voice(0, v)
    print(ics.read_voice(0).to_dict())
```

Simulator-native mode uses the same API, but starts `sim/sim --server` and talks to native simulator ICS2115 methods instead of PicoROM/debug-link. This avoids wall-clock serial timeouts; audio capture advances deterministic simulator cycles.

```py
from util.ics2115_remote import ICS2115Remote, Voice

with ICS2115Remote.open_sim(game="pgm_test") as ics:
    # Let the loaded program finish any startup sound-chip init before direct
    # register experiments, otherwise the running CPU/Z80 may overwrite voices.
    ics.sim.call("sim.run_cycles", {"count": 5_000_000})

    ics.play_voice(0, Voice.from_bios_trace())
    ics.open_audio()
    samples = ics.capture_audio_frames(2048)
```

Pass `transport="debug_link"` to `open_sim()` to drive the same TestROM/Z80-driver path that real hardware uses — this is the **conformance transport** for register-behavior tests (`docs/ics2115_register_matrix.md`): the same script runs against hardware (`ICS2115Remote.open`) and the simulator with the ICS2115 exercised through identical 68k/Z80 code. The native path bypasses the register interface entirely and is preferred only for audio/state introspection experiments.

In the simulator, `debug_link` data does not actually use the PicoROM ROM-mailbox byte protocol: 68k ROM reads go through `rom_cache`, which would serve stale mailbox bytes (the sim patches SDRAM behind the cache). Instead `testroms/debug_link.c` publishes a `RamComms` ring-buffer block in WORK_RAM (section `.comms_buffer`, magic `RFIF`); the simulator scans WORK_RAM for the magic on the first `debug_link.write`, sets `sim_active`, and streams request/response bytes through the rings (WORK_RAM is uncached dual-port BRAM, so simulator writes are coherent). The TestROM prefers the RAM block when `sim_active == 1` and falls back to the ROM mailbox otherwise, so the same TestROM binary works with PicoROM on hardware. Throughput is bounded by the page's once-per-vblank poll: ~1 frame of emulated time per synchronous request/response round trip; batch multiple requests per write to amortize (the page processes every complete request in a single poll).

Optional audio reader:

```py
with ICS2115Remote.open('pgm') as ics:
    ics.open_audio()          # optional serial port arg: open_audio('/dev/cu...')
    ics.play_voice(0, Voice.from_bios_trace())

    # Uses PGMAudioExtractor triggered capture mode. The firmware clears its
    # queue, discards a small number of internal DMA blocks, captures the next
    # frames, then returns to idle. No close/reopen cycle is required.
    samples = ics.capture_audio_frames(2, timeout=2.0)
    print(samples)            # [(left, right), ...]
```

The audio-only reusable module is `util/capture_audio.py`:

```py
from util.capture_audio import AudioStreamReader

with AudioStreamReader.open() as audio:
    samples = audio.capture_frames(2, timeout=2.0)
    blocks = audio.capture_blocks(4, timeout=2.0)
    audio.set_continuous()    # restore normal continuous streaming
```

## Wire protocol

Request header:

```text
'I' 'C' version seq cmd payload_len payload...
```

Response header:

```text
'i' 'c' version seq status payload_len payload...
```

All multi-byte fields are big-endian.  The Python side uses `read_exact()` for response headers and payloads.

Implemented commands:

```text
0x01 PING
0x02 INIT
0x10 READ_REG
0x11 WRITE_REG
0x20 READ_VOICE
0x21 WRITE_VOICE
0x30 GET_IRQ_COUNTS
0x31 RESET_IRQ_COUNTS
```

Responses only ACK success/error; writes do not perform automatic readback verification.

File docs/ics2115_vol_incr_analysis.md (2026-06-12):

# ICS2115 VMode / VIncr volume-ramp analysis

Input data: `vol_incr.csv`

Each row contains:

```text
vmode, vincr, sampled-left-audio...
```

The source sample is constant `-32768`, so the measured audio output is used as
a proxy for the hardware volume-table gain.  The analysis scripts stream the
large CSV and summarize only transitions/resets/periods.

Generated tools:

```text
audio_tests/analyze_vol_incr.py
audio_tests/plot_vol_incr.py
audio_tests/fit_vol_incr.py
```

Generated outputs:

```text
audio_tests/vol_incr.summary.csv
audio_tests/vol_incr.report.json
audio_tests/vol_incr_fit.report.json
audio_tests/vol_incr_transition_count.png
audio_tests/vol_incr_reset_count.png
audio_tests/vol_incr_reset_period_est.png
audio_tests/vol_incr_approx_index_rate.png
audio_tests/vol_incr_max_gain.png
```

Additional long capture for the slow `vmode[1:0] == 0` family:

```text
vol_incr_more_samples.csv
audio_tests/vol_incr_more_samples.summary.csv
audio_tests/vol_incr_more_samples.report.json
```

## High-level row classifications

From the 4096-row capture:

```text
wraps:                 2074
ramps_no_wrap:          866
silent_or_static_zero: 1156
```

## VMode bit observations

Working assumption: only `vmode[1:0]` is significant for the volume-envelope
rate family.  Treat differences caused by `vmode[2]` and `vmode[3]` in this
capture as phase/noise rather than separate modes.

Rationale from comparing modes that differ only in bits 2 or 3:

```text
vmode[1:0] == 0: modes 0,4,8,12
  classification and no-wrap behavior match; high-vincr transition spacing
  matches, but first transition/phase shifts.

vmode[1:0] == 1: modes 1,5,9,13
  measured periods match within about 2 samples where enough wraps exist;
  boundary rows differ when a wrap lands just inside/outside the capture.

vmode[1:0] == 2: modes 2,6,10,14
  measured period follows 65280/vincr for all four modes; mean period
  difference from flipping bits 2/3 is below 0.01 samples.

vmode[1:0] == 3: modes 3,7,11,15
  same behavior as the other odd family; measured periods match within about
  2 samples where enough wraps exist.
```

Bits 4..7 were not present in this dataset; assume they are also insignificant
until measured otherwise.

## Candidate formulas

### `vmode[1:0] == 2`

Observed equivalent modes:

```text
2, 6, 10, 14
```

These fit an extremely clean linear period:

```text
period_samples ~= 65280 / vincr
```

Equivalently:

```text
vol_acc full ramp span = 0xff00
vol_acc += vincr per output sample
```

Fit quality for rows with at least two detected wraps:

```text
mean absolute error: ~0.015 samples
max absolute error:  ~0.455 samples
```

Examples:

```text
vincr=8    period=8160
vincr=16   period=4080
vincr=64   period=1020
vincr=128  period=510
vincr=255  period=256
```

### `vmode[1:0] == 1` or `vmode[1:0] == 3`

Observed equivalent odd modes:

```text
1, 3, 5, 7, 9, 11, 13, 15
```

Both odd low-bit modes fit the same compact/floating-style VIncr rate with a 4x
larger ramp base:

```python
x = vincr & 0x7f
exp = x >> 5
mant = x & 0x1f

if exp == 0:
    step = (0x20 + mant) / 2
else:
    step = (0x20 + mant) << (exp - 1)

period_samples ~= 261120 / step
```

Fit quality for rows with at least two detected wraps:

```text
mean absolute error: ~0.3 samples
max absolute error:  ~3.9 samples
mean relative error: ~0.006%
```

Examples:

```text
vincr=128  x=0    step=16     period~=16320
vincr=160  x=32   step=32     period=8160
vincr=192  x=64   step=64     period=4080
vincr=224  x=96   step=128    period=2040
vincr=255  x=127  step=252    period~=1036.2
```

### `vmode[1:0] == 0`

Observed equivalent modes:

```text
0, 4, 8, 12
```

The original 16384-sample capture showed only a small partial ramp for high
`vincr` values.  The longer `vol_incr_more_samples.csv` capture contains 262144
samples for `vmode == 0` and confirms that only `vincr=224..255` wrap; all
`vincr <= 223` remain exactly zero/static across the whole longer window.

The refined period formula for this family is:

```python
if vincr >= 224:
    step = (vincr - 192) / 64
    period_samples = 65280 / step
                   = 65280 * 64 / (vincr - 192)
else:
    step = 0
```

Equivalently, for `vincr=224..255`:

```python
mant = vincr & 0x1f
period_samples = 4177920 / (0x20 + mant)
```

Examples from the longer capture:

```text
vincr=224  observed period=130560  predicted=130560
vincr=232  observed period=104448  predicted=104448
vincr=240  observed period=87040   predicted=87040
vincr=248  observed period=74624   predicted=74605.7
vincr=255  observed period=66304   predicted=66316.2
```

Fit quality over `vincr=224..255`:

```text
mean absolute period error: ~9.6 samples
max absolute period error:  ~23.3 samples
mean relative error:        ~0.011%
```

The exact observed periods are quantized by the finite number of wraps in the
capture, but the product `period * (vincr - 192)` clusters tightly around:

```text
65280 * 64 = 4177920
```

## HDL implementation notes

The HDL implementation should treat `REG_VMODE` (`0x12`) as a per-voice high-byte
register stored in `voice_state_t.vol_mode`.  Only `vol_mode[1:0]` selects the
rate family.

The top-level legacy `ramp_cnt`/`vol_incr[7:6]` divider should not gate envelope
updates.  The oscillator should update the envelope every processed output sample
using the per-voice step below, in internal `vol_acc` units:

```text
mode 0:
  if vincr >= 224: step = (0x20 + vincr[4:0]) << 4
  else:            step = 0

mode 1 or 3:
  if vincr == 0:   step = 0
  else if vincr[6:5] == 0: step = (0x20 + vincr[4:0]) << 7
  else if vincr[6:5] == 1: step = (0x20 + vincr[4:0]) << 8
  else if vincr[6:5] == 2: step = (0x20 + vincr[4:0]) << 9
  else:                    step = (0x20 + vincr[4:0]) << 10

mode 2:
  step = vincr << 10
```

`VOL_INCR` (`0x06`), `VOL_START` (`0x07`), `VOL_END` (`0x08`), and `VMODE`
(`0x12`) are high-byte voice-register accesses.  `VOL_START`/`VOL_END` high-byte
writes map to internal bits `[25:18]` with low fractional bits cleared.

## Next validation steps

1. Optionally capture VMode values with bits 4..7 set to validate the current
   assumption that only `vmode[1:0]` matters.
2. Compare predicted transition positions against raw sample transitions, not
   only reset periods.
3. Rerun simulator-vs-hardware audio capture comparisons with the HDL step logic.

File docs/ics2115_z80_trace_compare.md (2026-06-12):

# ICS2115 Z80 trace comparison

Captured 2026-05-20 with simulator server, FST traces (5-frame windows):

- Good BIOS-driver path (`z80_sound_test`, START pressed): `/tmp/z80_sound_start.fst`
- Debug driver path (`z80_ics_test`, PLAY pressed): `/tmp/z80_ics_play.fst`

The FSTs were loaded/opened by Surfer/WCP successfully.  The tabulation below was extracted from the FST host bus signals:

- `TOP.sim_top.pgm_inst.ics2115_addr[1:0]`
- `TOP.sim_top.pgm_inst.ics2115_wr_n`
- `TOP.sim_top.pgm_inst.ics2115_rd_n`
- `TOP.sim_top.pgm_inst.z80_dout[7:0]`
- `TOP.sim_top.pgm_inst.ics2115_dout[7:0]`
- `TOP.sim_top.pgm_inst.ics2115.reg_select[7:0]`
- `TOP.sim_top.pgm_inst.ics2115.osc_select[4:0]`
- `TOP.sim_top.pgm_inst.ics2115.active_osc[4:0]`

## Port convention

- port 1 = register select (`0x8001`)
- port 2 = low data (`0x8002`)
- port 3 = high data (`0x8003`)
- port 0 = status (`0x8000`)

## `z80_sound_test` / BIOS-driver path

Before voice programming, the BIOS driver is servicing timers:

```text
W p1 SEL 0x40 TIMER0
R p2 TIMER0 -> 0x9b
R p0 STATUS -> 0x00 / 0x81
W p1 SEL 0x43 TIMER_STAT/SCALE1
R p2 TIMER_STAT/SCALE1 -> 0x03
```

The actual voice-0 programming sequence after START is:

```text
W p1 SEL 0x4f OSC_SELECT
W p2 OSC_SELECT <= 0x00

W p1 SEL 0x01 OSC_FC
W p2 OSC_FC low  <= 0x55
W p3 OSC_FC high <= 0x01       ; FC = 0x0155

W p1 SEL 0x11 OSC_SADDR
W p3 OSC_SADDR <= 0x40

W p1 SEL 0x0b OSC_ACC_L
W p2 OSC_ACC_L low  <= 0x00
W p3 OSC_ACC_L high <= 0x60    ; ACC_L = 0x6000

W p1 SEL 0x0a OSC_ACC_H
W p2 OSC_ACC_H low  <= 0x3a
W p3 OSC_ACC_H high <= 0xb6    ; ACC_H = 0xb63a

W p1 SEL 0x03 OSC_START_L
W p2 OSC_START_L low  <= 0x00
W p3 OSC_START_L high <= 0x60  ; START_L = 0x6000

W p1 SEL 0x02 OSC_START_H
W p2 OSC_START_H low  <= 0x3a
W p3 OSC_START_H high <= 0xb6  ; START_H = 0xb63a

W p1 SEL 0x05 OSC_END_L
W p2 OSC_END_L low  <= 0x00
W p3 OSC_END_L high <= 0xb0    ; END_L = 0xb000

W p1 SEL 0x04 OSC_END_H
W p2 OSC_END_H low  <= 0x1e
W p3 OSC_END_H high <= 0xb8    ; END_H = 0xb81e

W p1 SEL 0x0c PAN
W p3 PAN <= 0x7f

W p1 SEL 0x09 VOL_ACC
W p2 VOL_ACC low  <= 0xf0
W p3 VOL_ACC high <= 0xdf      ; VOL_ACC = 0xdff0

W p1 SEL 0x00 OSC_CONF
W p3 OSC_CONF <= 0x20

W p1 SEL 0x0d VOL_CTRL
W p3 VOL_CTRL <= 0x03

W p1 SEL 0x10 OSC_CTL
W p3 OSC_CTL <= 0x00           ; key on
```

Simulator state after this sequence:

```text
active_osc = 31
reg_select = 0x40
osc_select = 0
voice0.state_on = true
voice0.osc_conf = 0x20
voice0.vol_ctrl = 0x03
voice0.osc_ctl  = 0x00
voice0.osc_saddr = 0x40
```

## `z80_ics_test` / debug-driver path

PLAY produces this voice-0 sequence:

```text
W p1 SEL 0x0e ACTIVE_OSC
W p3 ACTIVE_OSC <= 0x1f

W p1 SEL 0x4f OSC_SELECT
W p2 OSC_SELECT <= 0x00

W p1 SEL 0x4f OSC_SELECT
W p2 OSC_SELECT <= 0x00
W p1 SEL 0x10 OSC_CTL
W p3 OSC_CTL <= 0x0f           ; explicit stop before programming

W p1 SEL 0x4f OSC_SELECT
W p2 OSC_SELECT <= 0x00
W p1 SEL 0x00 OSC_CONF
W p3 OSC_CONF <= 0x08

W p1 SEL 0x4f OSC_SELECT
W p2 OSC_SELECT <= 0x00
W p1 SEL 0x01 OSC_FC
W p2 OSC_FC low  <= 0xa7
W p3 OSC_FC high <= 0x2a       ; FC = 0x2aa7 (RTL stores even 0x2aa6)

W p1 SEL 0x4f OSC_SELECT
W p2 OSC_SELECT <= 0x00
W p1 SEL 0x02 OSC_START_H
W p2 OSC_START_H low  <= 0x20
W p3 OSC_START_H high <= 0x21  ; START_H = 0x2120

W p1 SEL 0x4f OSC_SELECT
W p2 OSC_SELECT <= 0x00
W p1 SEL 0x03 OSC_START_L
W p3 OSC_START_L high <= 0x00  ; START_L high only

W p1 SEL 0x4f OSC_SELECT
W p2 OSC_SELECT <= 0x00
W p1 SEL 0x04 OSC_END_H
W p2 OSC_END_H low  <= 0x8b
W p3 OSC_END_H high <= 0x2a    ; END_H = 0x2a8b

W p1 SEL 0x4f OSC_SELECT
W p2 OSC_SELECT <= 0x00
W p1 SEL 0x05 OSC_END_L
W p3 OSC_END_L high <= 0x00    ; END_L high only

W p1 SEL 0x4f OSC_SELECT
W p2 OSC_SELECT <= 0x00
W p1 SEL 0x06 VOL_INCR
W p2 VOL_INCR low <= 0x00      ; differs from high-byte style used by many voice regs

W p1 SEL 0x4f OSC_SELECT
W p2 OSC_SELECT <= 0x00
W p1 SEL 0x07 VOL_START
W p2 VOL_START low <= 0xff

W p1 SEL 0x4f OSC_SELECT
W p2 OSC_SELECT <= 0x00
W p1 SEL 0x08 VOL_END
W p2 VOL_END low <= 0xff

W p1 SEL 0x4f OSC_SELECT
W p2 OSC_SELECT <= 0x00
W p1 SEL 0x09 VOL_ACC
W p2 VOL_ACC low  <= 0xff
W p3 VOL_ACC high <= 0xff      ; VOL_ACC = 0xffff

W p1 SEL 0x4f OSC_SELECT
W p2 OSC_SELECT <= 0x00
W p1 SEL 0x0a OSC_ACC_H
W p2 OSC_ACC_H low  <= 0x20
W p3 OSC_ACC_H high <= 0x21    ; ACC_H = 0x2120

W p1 SEL 0x4f OSC_SELECT
W p2 OSC_SELECT <= 0x00
W p1 SEL 0x0b OSC_ACC_L
W p2 OSC_ACC_L low  <= 0x00
W p3 OSC_ACC_L high <= 0x00    ; ACC_L = 0x0000

W p1 SEL 0x4f OSC_SELECT
W p2 OSC_SELECT <= 0x00
W p1 SEL 0x0c PAN
W p3 PAN <= 0x7f

W p1 SEL 0x4f OSC_SELECT
W p2 OSC_SELECT <= 0x00
W p1 SEL 0x0d VOL_CTRL
W p3 VOL_CTRL <= 0x00

W p1 SEL 0x4f OSC_SELECT
W p2 OSC_SELECT <= 0x00
W p1 SEL 0x11 OSC_SADDR
W p3 OSC_SADDR <= 0x00

W p1 SEL 0x4f OSC_SELECT
W p2 OSC_SELECT <= 0x00
W p1 SEL 0x10 OSC_CTL
W p3 OSC_CTL <= 0x00           ; key on
```

Simulator state after this sequence:

```text
active_osc = 31
reg_select = 0x10
osc_select = 0
voice0.state_on = true
voice0.osc_conf = 0x08
voice0.vol_ctrl = 0x01      ; RTL readback/state after writing 0x00
voice0.osc_ctl  = 0x00
voice0.osc_saddr = 0x00
```

## Main differences

1. The BIOS path selects voice once and then writes the voice registers.  The debug path re-selects voice 0 before every voice register.  This works in the simulator, but it is not BIOS-like.

2. The BIOS path does not write `ACTIVE_OSC` during this START trace.  It relies on prior chip init/default state.  The debug path writes `0x0e = 0x1f` immediately before PLAY.

3. The BIOS path uses:
   - `OSC_CONF = 0x20`
   - `VOL_CTRL = 0x03`
   - `VOL_ACC = 0xdff0`
   - `OSC_SADDR = 0x40`

   The debug path uses:
   - `OSC_CONF = 0x08`
   - `VOL_CTRL = 0x00`
   - `VOL_ACC = 0xffff`
   - `OSC_SADDR = 0x00`

4. Earlier debug paths wrote `VOL_INCR`, `VOL_START`, and `VOL_END` through the low data port (`0x8002`).  Hardware testing and the current RTL treat these as high-byte voice-register accesses via `0x8003`; debug/test code should use `Z80_ICS_WIDTH_UPPER8` for `0x06`, `0x07`, and `0x08`.

5. The BIOS path starts from a known-good wave-table entry.  The debug path programs custom sample addresses directly.  The simulator can play this, but for hardware isolation the next test should mimic the known-good BIOS wave entry exactly.

## Suggested next hardware test

Make `z80_ics_test` PLAY program voice 0 with the exact BIOS-driver values from the good trace:

```text
voice = 0
FC        = 0x0155
SADDR     = 0x40
ACC_L     = 0x6000
ACC_H     = 0xb63a
START_L   = 0x6000
START_H   = 0xb63a
END_L     = 0xb000
END_H     = 0xb81e
PAN       = 0x7f
VOL_ACC   = 0xdff0
OSC_CONF  = 0x20
VOL_CTRL  = 0x03
OSC_CTL   = 0x00
```

Also avoid re-selecting `0x4f` before every single register for this specific hardware-parity test; select voice once, then emit the same register order as the BIOS trace.

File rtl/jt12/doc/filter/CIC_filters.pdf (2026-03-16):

## CIC filters

By
Sylas Ashton

## Overview

- Over‐Sampling and Averaging
- Effective Number of Bits(ENOB)
- Moving Average Filter
- Comb‐Integrator Moving Average Filter
- Re‐arranging to CIC filter
- Nth Order CIC filter
- Implementation
- Frequency Response of the CIC filter

## Over‐Sampling and Averaging

- Increases Bit resolution
- Increasing N bits out requires 2^N samples
- Increasing Effective Number of Bits(ENOB) – Fos=Fout*2^(2n) => n=log4(Fos/Fout)=log4(D)
- For 50MHz sampling and 16kHz output
– Fos/Fout = 3125
– 11.6 Bits out
– 5.8 ENOB

## Getting 16 ENOB

- Add 2 more averaging filters
– Bit width = 11.6*3=34.8
– ENOB = 3*5.8=17.414 bits
- Resource usage grows exponentially

## Basic Moving Average w/ Gain

- Directly sums last D bits – D*Bit_width of bits of
storage
– D adders

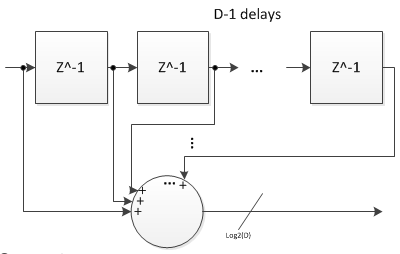
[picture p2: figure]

– Log2(D)bits output latch for decimator
– 3 averaging filters in series requires D+D*log2(D)+D*log2(D)*2 bits of storage and 3*D adders

### Comb‐Integrator Moving Average Filter

- Still needs same amount of storage
- Needs one adder/subtractor and one integrator

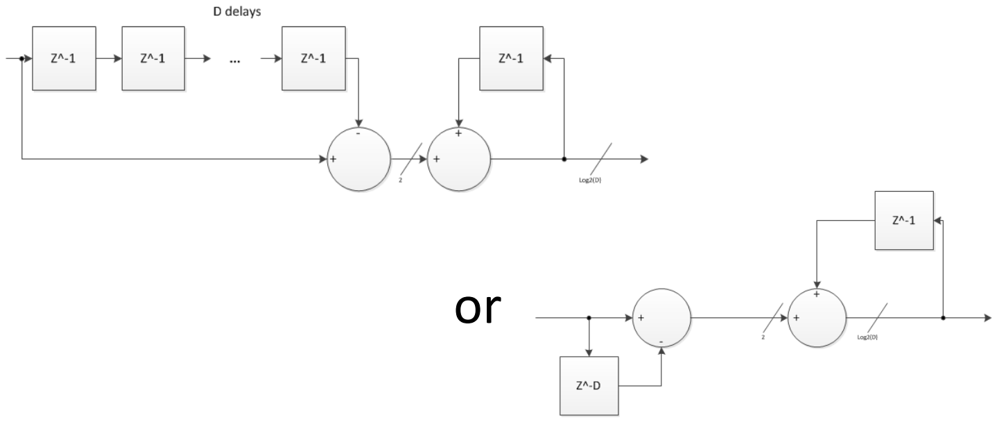
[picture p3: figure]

## Re‐arrange LTI systems

- Integrate, then Decimate, then Comb

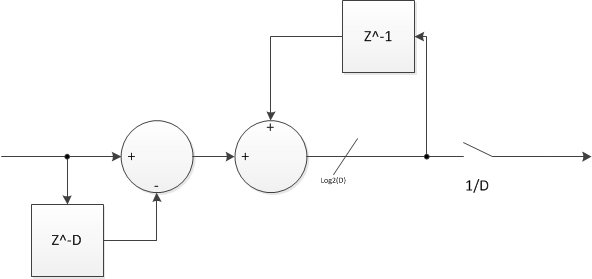
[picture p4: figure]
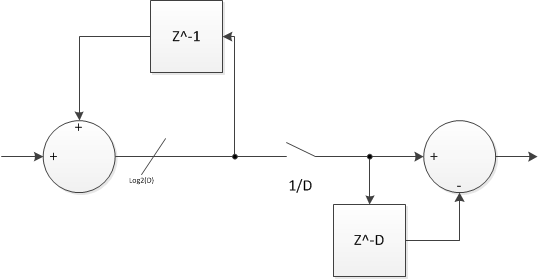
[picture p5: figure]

- If the Comb delay is the same as the decimation time, the delay D is the last sample from the decimator, reducing storage by a factor of D

=>

### Nth order Cascade Integrated Comb Filter

- Take N moving average filters in sequence with decimation at the end
– Rearrange all integrators first, and comb filters last, with the decimator in the middle
- Integrator overflows are removed by combs if unsigned math is used and the bit width is at least N*log2(D)

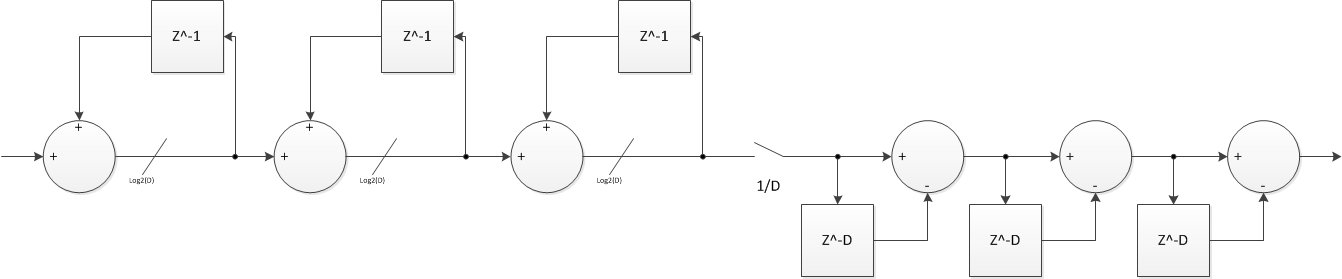
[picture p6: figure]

## Implementation

- All logic runs on main clock
- All Integrators are always enabled
- Registers for the decimator and comb filters are enabled every Dth cycle(D=3125)
- Uses (2*N+1)*N*log
2(D) bits of storage

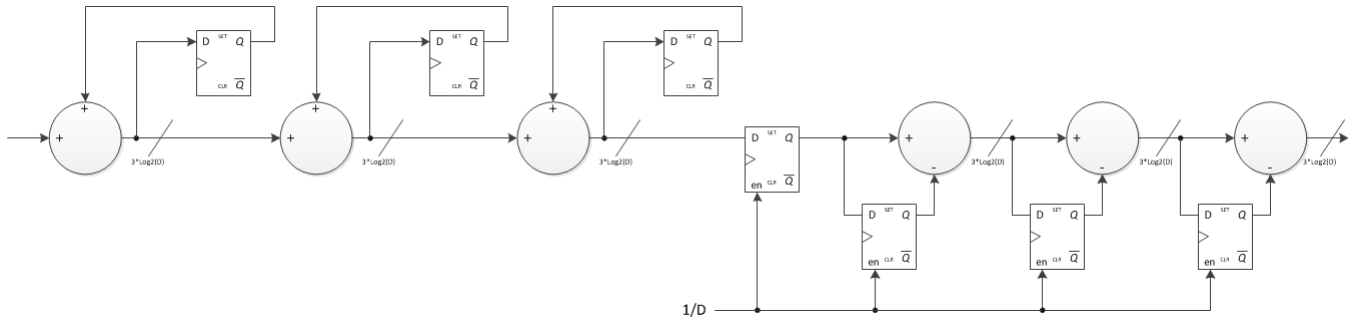
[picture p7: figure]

## Frequency Response

- Gain = abs(sin(pi*f*D)/sin(pi*f))^N
- Phase is linear
- For 3rd order filter with 50MHz sample rate and 16kHz output rate
– 3dB at 4250Hz
– 11dB drop at 8kHz,
– min 40dB suppression above 16kHz

## Frequency Response

- 1st order CIC filter response – D=8

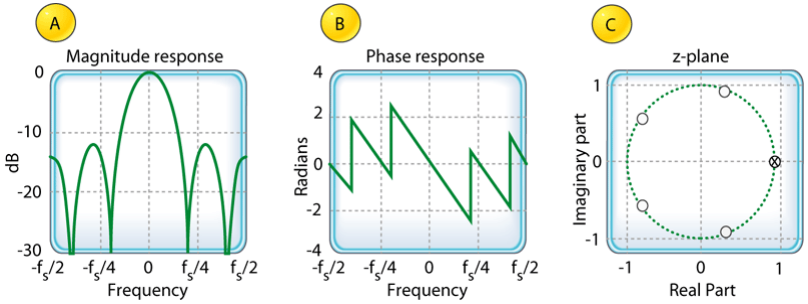
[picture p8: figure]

## Frequency Response

- 3rd order CIC filter frequency response – D=R=8

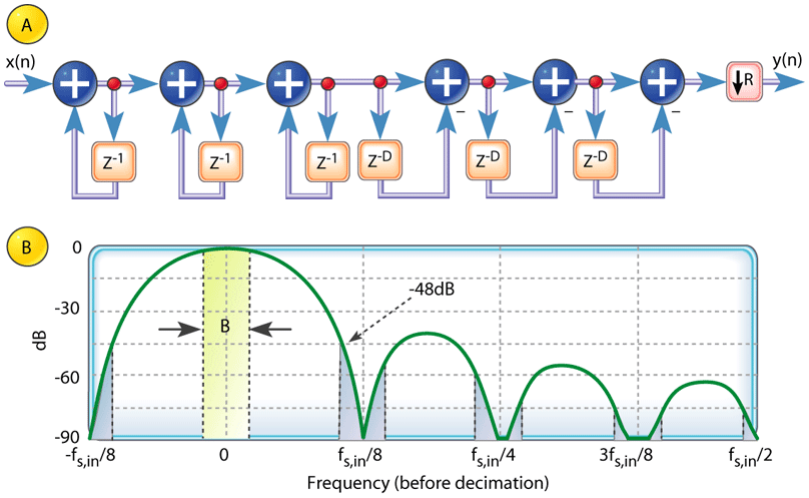
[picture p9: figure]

## Frequency Response

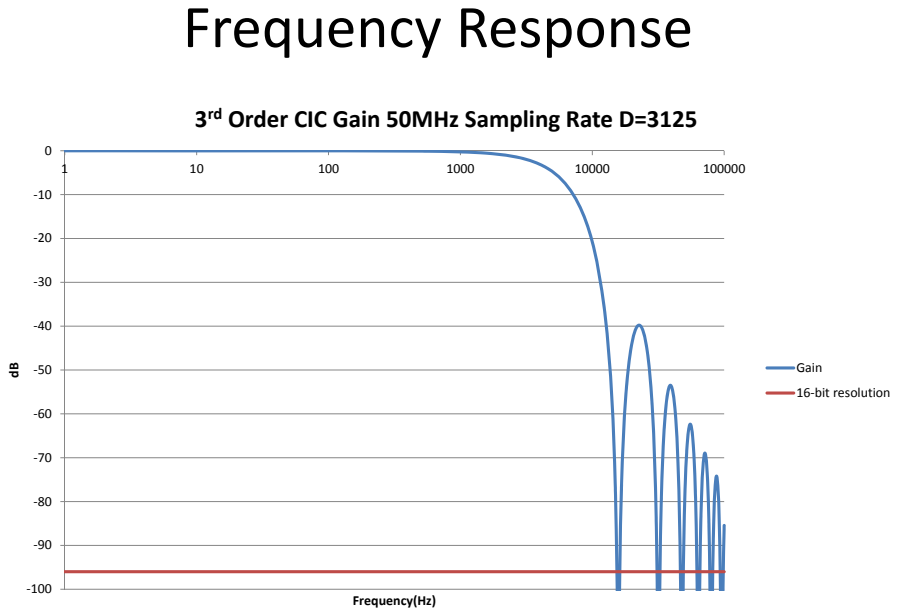
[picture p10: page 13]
Frequency(Hz); Gain; 16‐bit resolution

3rd Order CIC Gain 50MHz Sampling Rate D=3125

## References

- http://www.embedded.com/design/configurable‐systems/4006446/Understanding‐cascaded‐ integrator‐comb‐filters
- http://dspguru.com/sites/dspguru/files/cic.pdf
- http://home.mit.bme.hu/~kollar/papers/cic.pdf

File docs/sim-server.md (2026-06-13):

# Simulator server interface

The simulator can run as a persistent, agent-friendly control server over stdio.

## Start the server

```bash
cd sim
./sim --server
```

Alias:

```bash
./sim --control-stdio
```

In server mode:

- requests are read from `stdin`
- one JSON object is expected per line
- one JSON response is written to `stdout` per request
- simulator logs and incidental output go to `stderr`

This makes `stdout` safe for machine parsing.

## Request format

Each request must be a single-line JSON object:

```json
{"id":1,"method":"sim.status","params":{}}
```

Fields:

- `id` - required numeric request id, echoed in the response
- `method` - required string method name
- `params` - optional object of method parameters

## Response format

Successful response:

```json
{"id":1,"ok":true,"result":{"initialized":true}}
```

Error response:

```json
{"id":1,"ok":false,"error":{"code":"bad_request","message":"Missing field: method"}}
```

Fields:

- `id` - request id, or `0` if parsing failed before an id was available
- `ok` - boolean success flag
- `result` - method-specific payload on success
- `error.code` - stable machine-readable error code
- `error.message` - human-readable error text

## Lifecycle

Typical session:

1. `sim.initialize`
2. `sim.load_game` or `sim.load_mra`
3. optional `sim.reset`
4. query and control methods like `sim.run_cycles`, `cpu.get_state`, `memory.read`
5. optional `gui.get_state`, `gui.set_override`, or `gui.press_button` when interacting with the exported TestROM GUI
6. optional `ics2115.get_state` when inspecting sound-chip voice/global state
7. optional `audio_capture.start` / `audio_capture.stop` when capturing simulator audio packets
8. `sim.shutdown` when finished

## Methods

### `sim.initialize`

Initialize the simulator runtime.

Request:

```json
{"id":1,"method":"sim.initialize","params":{"headless":true}}
```

Params:

- `headless` - optional boolean, defaults to `true`

Result:

```json
{}
```

### `sim.shutdown`

Shut down the simulator runtime.

Request:

```json
{"id":2,"method":"sim.shutdown","params":{}}
```

Result:

```json
{}
```

### `sim.status`

Return current simulator status.

Request:

```json
{"id":3,"method":"sim.status","params":{}}
```

Result:

```json
{
  "initialized": true,
  "running": false,
  "paused": false,
  "trace_active": false,
  "headless": true,
  "total_ticks": 0,
  "game_name": "pgm"
}
```

### `sim.load_game`

Load a named built-in game target.

Request:

```json
{"id":4,"method":"sim.load_game","params":{"name":"pgm"}}
```

Params:

- `name` - game short name

Result:

```json
{}
```

Possible errors include:

- `unknown_game`
- `load_failed`

### `sim.load_mra`

Load an MRA file.

Request:

```json
{"id":5,"method":"sim.load_mra","params":{"path":"../releases/finalb.mra"}}
```

Params:

- `path` - path to the MRA file

Result:

```json
{}
```

### `sim.reset`

Assert reset for a fixed number of cycles.

Request:

```json
{"id":6,"method":"sim.reset","params":{"cycles":100}}
```

Params:

- `cycles` - number of cycles to hold reset

Result:

```json
{}
```

### `sim.run_cycles`

Run a fixed number of cycles.

Request:

```json
{"id":7,"method":"sim.run_cycles","params":{"count":1000}}
```

Params:

- `count` - cycles to execute

Result:

```json
{
  "reason": "completed",
  "ticks_executed": 1000,
  "frames_executed": 0
}
```

### `sim.run_frames`

Run a fixed number of video frames using vblank transitions.

Request:

```json
{"id":8,"method":"sim.run_frames","params":{"count":1}}
```

Params:

- `count` - frames to execute

Result:

```json
{
  "reason": "completed",
  "ticks_executed": 896120,
  "frames_executed": 1
}
```

### `sim.run_until`

Run until a condition is satisfied or until a stop reason occurs.

For `signal_*` conditions, the signal may be either:

- one of the built-in aliases like `vblank`
- a VPI-resolved hierarchical signal name such as `sim_top.vblank` or `pgm_inst.cpu_word_addr`

For VPI lookup, the controller tries these forms automatically:

- exact name provided
- `TOP.<name>`
- `sim_top.<name>`
- `TOP.sim_top.<name>`

Note: the default VPI build does **not** use `--public-flat-rw`, so only a subset of internal signals may be visible through VPI.
Built-in aliases remain available regardless.

Request:

```json
{
  "id": 9,
  "method": "sim.run_until",
  "params": {
    "condition": {
      "type": "cpu_pc_equals",
      "value": 256
    },
    "timeout_cycles": 1000000
  }
}
```

Params:

- `condition` - required condition object
- `timeout_cycles` - optional cycle timeout

Result:

```json
{
  "reason": "condition_met",
  "ticks_executed": 2048,
  "frames_executed": 0
}
```

#### Condition types

Supported condition `type` values:

- `signal_equals`
- `signal_not_equals`
- `signal_less_than`
- `signal_less_equal`
- `signal_greater_than`
- `signal_greater_equal`
- `cpu_pc_equals`
- `cpu_pc_in_range`
- `cpu_pc_out_of_range`
- `and`
- `or`
- `not`

Condition fields depend on the type:

##### Signal comparisons

```json
{"type":"signal_equals","signal":"vblank","value":1}
```

VPI-resolved example:

```json
{"type":"signal_not_equals","signal":"pgm_inst.cpu_word_addr","value":0}
```

Fields:

- `signal` - signal name
- `value` - expected integer value

##### Program counter equality

```json
{"type":"cpu_pc_equals","value":4096}
```

##### Program counter range

Either `start`/`end` or internal `value`/`value2` mapping is accepted by the protocol parser.

```json
{"type":"cpu_pc_in_range","start":4096,"end":8192}
```

##### Boolean composition

```json
{
  "type": "and",
  "children": [
    {"type":"signal_equals","signal":"vblank","value":1},
    {"type":"cpu_pc_in_range","start":4096,"end":8192}
  ]
}
```

`not` uses the first child:

```json
{
  "type": "not",
  "children": [
    {"type":"signal_equals","signal":"reset","value":1}
  ]
}
```

#### Run stop reasons

Possible `reason` values:

- `completed`
- `condition_met`
- `watchpoint_hit`
- `timeout`
- `error`

## CPU and memory inspection

### `cpu.get_state`

Request:

```json
{"id":10,"method":"cpu.get_state","params":{}}
```

Result:

```json
{
  "pc": 256,
  "registers": [0,0,0,0,0,0,0,0,0,0,0,0,0,0,0,0,0],
  "disasm": "move.w d0, d1"
}
```

### `memory.list_regions`

Request:

```json
{"id":11,"method":"memory.list_regions","params":{}}
```

Result:

```json
[
  "BIOS_ROM",
  "PROGRAM_ROM",
  "PALETTE_RAM",
  "VIDEO_RAM",
  "WORK_RAM",
  "AUDIO_RAM",
  "TILE_ROM",
  "MUSIC_ROM",
  "B_ROM",
  "A_ROM"
]
```

### `memory.read`

Read raw bytes from a named region.

Request:

```json
{"id":12,"method":"memory.read","params":{"region":"WORK_RAM","address":0,"size":16}}
```

Params:

- `region` - one of the region names above
- `address` - byte address within the region
- `size` - number of bytes to read

Result:

```json
{
  "region": "WORK_RAM",
  "address": 0,
  "data_hex": "000102030405060708090a0b0c0d0e0f"
}
```

### `memory.write`

Write raw bytes to a named region.

Request:

```json
{"id":13,"method":"memory.write","params":{"region":"WORK_RAM","address":0,"data_hex":"01020304"}}
```

Params:

- `region` - region name
- `address` - byte address within the region
- `data_hex` - even-length hex byte string

Result:

```json
{}
```

## Signal inspection

### `signal.read`

Read a signal value.

Request:

```json
{"id":14,"method":"signal.read","params":{"name":"vblank"}}
```

Result:

```json
{"name":"vblank","value":0,"width":1,"value_hex":"0"}
```

Names may be:

- built-in aliases:
  - `vblank`
  - `hblank`
  - `reset`
  - `rom_load_busy`
  - `ss_state_out`
- VPI hierarchical names, for example:
  - `sim_top.vblank`
  - `pgm_inst.cpu_word_addr`
  - `TOP.sim_top.pgm_inst.cpu_word_addr`

Notes:

- VPI reads currently support signals up to 64 bits wide.
- Signals containing X/Z bits currently return an error.
- Not every internal signal is necessarily exposed by the default VPI build.

### `signal.list`

Enumerate built-in aliases and VPI-visible signals available at runtime.

Request:

```json
{"id":14,"method":"signal.list","params":{}}
```

Result:

```json
{
  "signals": [
    {"name":"vblank","width":1,"kind":"alias","source":"builtin"},
    {"name":"sim_top.pgm_inst.cpu_word_addr","width":24,"kind":"reg","source":"vpi"}
  ]
}
```

This is the best way to discover what VPI signals are actually available in the current build.

## State management

### `state.list`

Request:

```json
{"id":15,"method":"state.list","params":{}}
```

Result:

```json
{"states":["000.pgmstate","001.pgmstate"]}
```

### `state.save`

Request:

```json
{"id":16,"method":"state.save","params":{"filename":"000.pgmstate"}}
```

Result:

```json
{}
```

### `state.load`

Request:

```json
{"id":17,"method":"state.load","params":{"filename":"000.pgmstate"}}
```

Result:

```json
{}
```

## Trace and video

### `trace.start`

Request:

```json
{"id":18,"method":"trace.start","params":{"filename":"trace.fst","depth":4}}
```

Params:

- `filename` - trace output path
- `depth` - optional trace depth, defaults to `1`

Result:

```json
{}
```

### `trace.stop`

Request:

```json
{"id":19,"method":"trace.stop","params":{}}
```

Result:

```json
{}
```

### `audio_capture.start`

Start binary audio packet capture using the same packet format documented for the hardware extractor protocol.

Request:

```json
{"id":20,"method":"audio_capture.start","params":{"filename":"capture.bin"}}
```

Params:

- `filename` - output file path for the captured packet stream

Result:

```json
{}
```

Notes:

- This replaces the old simulator CLI/environment-based capture control.
- Capture starts immediately and continues until `audio_capture.stop` or `sim.shutdown`.
- The output can be decoded with `utils/capture_stream.py`.

### `audio_capture.stop`

Stop binary audio packet capture and flush any buffered audio/status packets.

Request:

```json
{"id":21,"method":"audio_capture.stop","params":{}}
```

Result:

```json
{}
```

### Audio capture workflow example

Capture 120 frames of simulator audio to a binary packet stream:

```text
> {"id":1,"method":"sim.initialize","params":{"headless":true}}
> {"id":2,"method":"sim.load_game","params":{"name":"pgm"}}
> {"id":3,"method":"sim.reset","params":{"cycles":100}}
> {"id":4,"method":"audio_capture.start","params":{"filename":"/tmp/pgm.bin"}}
> {"id":5,"method":"sim.run_frames","params":{"count":120}}
> {"id":6,"method":"audio_capture.stop","params":{}}
> {"id":7,"method":"sim.shutdown","params":{}}
```

Decode the captured packet stream into WAV using the shared host tool:

```bash
python3 utils/capture_stream.py /tmp/pgm.wav --input /tmp/pgm.bin
```

### `video.screenshot`

Request:

```json
{"id":20,"method":"video.screenshot","params":{"path":"frame.png"}}
```

Result:

```json
{"path":"frame.png"}
```

## ICS2115 debug state

### `ics2115.get_state`

Return the current ICS2115 state for simulator/debug tooling. The payload includes global chip state, IRQ summaries, timer state, host/ROM/audio status, and all 32 decoded voice records.

Request:

```json
{"id":30,"method":"ics2115.get_state","params":{}}
```

Top-level result fields include:

- `active_osc`, `osc_select`, `reg_select`, `vmode`
- `irq_pending`, `irq_enabled`, `irq_on`
- `osc_irq_pending_count`, `vol_irq_pending_count`, `state_on_count`, `stop_count`
- `seq_state`, `seq_voice_idx`, `sample_tick`
- `host` object: `dout`, `cs_n`, `rd_n`, `wr_n`, `irq`, `ready`, `reset_n`
- `rom` object: `addr`, `data`, `data_valid`
- `audio` object: `left`, `right`, `valid`
- `timers` array with two timer records
- `voices` array with 32 voice records

Each voice record includes:

- oscillator fields: `osc_acc`, `osc_fc`, `osc_start`, `osc_end`, `osc_saddr`, `osc_conf`, `osc_ctl`
- volume fields: `vol_acc`, `vol_start`, `vol_end`, `vol_incr`, `vol_pan`, `vol_ctrl`, `vol_mode`
- runtime fields: `state_on`

### `ics2115.write_voice`

Simulator-native debug method used by `util/ics2115_remote.py` simulator mode. It directly updates one decoded voice RAM entry using the same internal fields returned by `ics2115.get_state`.

Request fields: `index`, `osc_acc`, `osc_fc`, `osc_start`, `osc_end`, `osc_saddr`, `osc_conf`, `osc_ctl`, `vol_acc`, `vol_start`, `vol_end`, `vol_incr`, `vol_pan`, `vol_ctrl`, `vol_mode`, `state_on`.

### `ics2115.write_global`

Simulator-native debug method for selected global fields.

```json
{"id":31,"method":"ics2115.write_global","params":{"name":"active_osc","value":31}}
```

Supported names: `active_osc`, `osc_select`, `reg_select`, `mode`/`vmode`, `irq_enable`/`irq_enabled`.

## TestROM GUI mirroring

When a test ROM exports `gui_data` in `WORK_RAM` at `0x0a00`, the simulator checks it on each vblank and mirrors it into an ImGui window named `TestROM GUI`.

The data is considered safe to consume only if all of these are true:

- `start_magic == 0xAB7D`
- `end_magic == 0xAB7D`
- `count > 0`
- `count <= 32`
- `lock == 0`

When safe, the simulator copies the GUI data, renders an ImGui version of it, and writes changed `override_value` fields back into the work RAM copy.

### `gui.get_state`

Return the most recently mirrored TestROM GUI state.

Request:

```json
{"id":21,"method":"gui.get_state","params":{}}
```

Result:

```json
{
  "available": true,
  "address": 2560,
  "last_sync_ticks": 8384011,
  "entries": [
    {
      "index": 0,
      "label": "CTRL",
      "type": 2,
      "type_name": "u16",
      "value": 13,
      "override_value": 13
    }
  ]
}
```

Fields:

- `available` - whether a safe GUI snapshot is currently available
- `address` - source address in `WORK_RAM` (`0x0a00` / `2560`)
- `last_sync_ticks` - simulator tick when the last safe snapshot was mirrored
- `entries` - copied GUI entries

Entry fields:

- `index` - entry index in the exported array
- `label` - GUI label text
- `type` - raw numeric type from test ROMs
- `type_name` - decoded type name such as `u8`, `u16`, `bits16`, `bool`, or `button`
- `value` - current value from the test ROM GUI entry
- `override_value` - current override value mirrored by the simulator

### `gui.set_override`

Set an entry's `override_value` by `index` or `label`.

Request by index:

```json
{"id":22,"method":"gui.set_override","params":{"index":0,"value":14}}
```

Request by label:

```json
{"id":23,"method":"gui.set_override","params":{"label":"CTRL","value":14}}
```

Params:

- exactly one of `index` or `label`
- `value` - 16-bit value to write to the entry's `override_value`

Result:

```json
{"applied":true}
```

Notes:

- `applied=true` means the write was applied immediately to a currently safe GUI snapshot
- if the GUI is temporarily unavailable, the request fails with `gui_unavailable`

### `gui.press_button`

Pulse a button entry by setting its `override_value` to `1` and then automatically returning it to `0` on the next safe GUI sync.

Request by label:

```json
{"id":24,"method":"gui.press_button","params":{"label":"BUTTON 1"}}
```

Request by index:

```json
{"id":25,"method":"gui.press_button","params":{"index":3}}
```

Result:

```json
{"applied":true}
```

Notes:

- this only works for entries whose `type_name` is `button`
- pulse writes for non-button entries fail with `gui_unavailable`

## Input control

### `input.set_dipswitch`

Turn one DIP switch on or off. The `switch` field is 1-based (`1` through `8`).

Request:

```json
{"id":21,"method":"input.set_dipswitch","params":{"switch":1,"on":true}}
```

Turn the same switch back off:

```json
{"id":22,"method":"input.set_dipswitch","params":{"switch":1,"on":false}}
```

The method also accepts zero-based `index` (`0` through `7`) and `enabled` as an alias for `on`.

Returns the current 8-bit DIP switch value:

```json
{"value":1}
```

## Error handling notes

Common error codes include:

- `bad_request`
- `unknown_method`
- `not_initialized`
- `unknown_game`
- `load_failed`
- `invalid_region`
- `invalid_signal`
- `save_state_failed`
- `load_state_failed`
- `screenshot_failed`
- `gui_unavailable`

## Example session

```text
> {"id":1,"method":"sim.initialize","params":{"headless":true}}
< {"id":1,"ok":true,"result":{}}

> {"id":2,"method":"sim.load_game","params":{"name":"pgm"}}
< {"id":2,"ok":true,"result":{}}

> {"id":3,"method":"sim.reset","params":{"cycles":100}}
< {"id":3,"ok":true,"result":{}}

> {"id":4,"method":"audio_capture.start","params":{"filename":"/tmp/pgm.bin"}}
< {"id":4,"ok":true,"result":{}}

> {"id":5,"method":"sim.run_until","params":{"condition":{"type":"signal_equals","signal":"vblank","value":1},"timeout_cycles":1000000}}
< {"id":5,"ok":true,"result":{"reason":"condition_met","ticks_executed":447980,"frames_executed":0}}

> {"id":6,"method":"audio_capture.stop","params":{}}
< {"id":6,"ok":true,"result":{}}

> {"id":7,"method":"gui.get_state","params":{}}
< {"id":7,"ok":true,"result":{"available":true,"address":2560,"last_sync_ticks":447980,"entries":[...]}}

> {"id":8,"method":"cpu.get_state","params":{}}
< {"id":8,"ok":true,"result":{"pc":256,"registers":[...],"disasm":"..."}}
```

## Agent usage guidance

For agent control, prefer:

- one long-lived `./sim --server` process per task
- monotonically increasing request ids
- `sim.status` after setup failures
- `sim.run_until` for synchronization instead of polling with many tiny `sim.run_cycles` calls
- `memory.read` / `signal.read` for explicit observations

Avoid mixing machine-readable protocol traffic with ad-hoc terminal interaction on the same stdio stream.

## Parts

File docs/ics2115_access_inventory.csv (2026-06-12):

source | file | line | function | reg | width | rw | value | notes
pgm_bios_z80 | pgm_bios_z80_raw_decompiled.c | 846 | InitializeSoundChannels@ram:1050 | 0x4f | LOWER8 | W | DYNAMIC | WriteICSSelectOscillator; value expr: voice_slot
pgm_bios_z80 | pgm_bios_z80_raw_decompiled.c | 847 | InitializeSoundChannels@ram:1050 | 0x0d | UPPER8 | R
pgm_bios_z80 | pgm_bios_z80_raw_decompiled.c | 852 | InitializeSoundChannels@ram:1050 | 0x0d | UPPER8 | W | DYNAMIC | value expr: bVar2
pgm_bios_z80 | pgm_bios_z80_raw_decompiled.c | 853 | InitializeSoundChannels@ram:1050 | 0x07 | UPPER8 | W | 0x01
pgm_bios_z80 | pgm_bios_z80_raw_decompiled.c | 854 | InitializeSoundChannels@ram:1050 | 0x08 | UPPER8 | W | 0x01
pgm_bios_z80 | pgm_bios_z80_raw_decompiled.c | 855 | InitializeSoundChannels@ram:1050 | 0x10 | UPPER8 | W | 0x0f
pgm_bios_z80 | pgm_bios_z80_raw_decompiled.c | 857 | InitializeSoundChannels@ram:1050 | 0x0d | UPPER8 | R
pgm_bios_z80 | pgm_bios_z80_raw_decompiled.c | 860 | InitializeSoundChannels@ram:1050 | 0x0d | UPPER8 | W | 0x03
pgm_bios_z80 | pgm_bios_z80_raw_decompiled.c | 861 | InitializeSoundChannels@ram:1050 | 0x00 | UPPER8 | W | 0x00
pgm_bios_z80 | pgm_bios_z80_raw_decompiled.c | 920 | ProgramSoundChannelRegisters@ram:10b9 | 0x4f | LOWER8 | W | DYNAMIC | WriteICSSelectOscillator; value expr: puVar3[-6]
pgm_bios_z80 | pgm_bios_z80_raw_decompiled.c | 924 | ProgramSoundChannelRegisters@ram:10b9 | 0x01 | WORD | W | DYNAMIC | value expr: value
pgm_bios_z80 | pgm_bios_z80_raw_decompiled.c | 926 | ProgramSoundChannelRegisters@ram:10b9 | 0x11 | UPPER8 | W | DYNAMIC | value expr: **(byte **)(puVar3 + -4)
pgm_bios_z80 | pgm_bios_z80_raw_decompiled.c | 929 | ProgramSoundChannelRegisters@ram:10b9 | 0x0b | WORD | W | DYNAMIC | value expr: *(ushort *)(*(short *)(puVar3 + -4) + 4)
pgm_bios_z80 | pgm_bios_z80_raw_decompiled.c | 931 | ProgramSoundChannelRegisters@ram:10b9 | 0x0a | WORD | W | DYNAMIC | value expr: *(ushort *)(*(short *)(puVar3 + -4) + 6)
pgm_bios_z80 | pgm_bios_z80_raw_decompiled.c | 935 | ProgramSoundChannelRegisters@ram:10b9 | 0x0b | WORD | W | DYNAMIC | value expr: *(ushort *)(*(short *)(puVar3 + -4) + 8)
pgm_bios_z80 | pgm_bios_z80_raw_decompiled.c | 937 | ProgramSoundChannelRegisters@ram:10b9 | 0x0a | WORD | W | DYNAMIC | value expr: *(ushort *)(*(short *)(puVar3 + -4) + 10)
pgm_bios_z80 | pgm_bios_z80_raw_decompiled.c | 940 | ProgramSoundChannelRegisters@ram:10b9 | 0x03 | WORD | W | DYNAMIC | value expr: *(ushort *)(*(short *)(puVar3 + -4) + 4)
pgm_bios_z80 | pgm_bios_z80_raw_decompiled.c | 942 | ProgramSoundChannelRegisters@ram:10b9 | 0x02 | WORD | W | DYNAMIC | value expr: *(ushort *)(*(short *)(puVar3 + -4) + 6)
pgm_bios_z80 | pgm_bios_z80_raw_decompiled.c | 944 | ProgramSoundChannelRegisters@ram:10b9 | 0x05 | WORD | W | DYNAMIC | value expr: *(ushort *)(*(short *)(puVar3 + -4) + 8)
pgm_bios_z80 | pgm_bios_z80_raw_decompiled.c | 946 | ProgramSoundChannelRegisters@ram:10b9 | 0x04 | WORD | W | DYNAMIC | value expr: *(ushort *)(*(short *)(puVar3 + -4) + 10)
pgm_bios_z80 | pgm_bios_z80_raw_decompiled.c | 948 | ProgramSoundChannelRegisters@ram:10b9 | 0x0c | UPPER8 | W | DYNAMIC | value expr: z80_voice_pan_table[(byte)puVar3[8]]
pgm_bios_z80 | pgm_bios_z80_raw_decompiled.c | 950 | ProgramSoundChannelRegisters@ram:10b9 | 0x09 | WORD | W | DYNAMIC | value expr: z80_wave_frequency_table[(byte)puVar3[6]]
pgm_bios_z80 | pgm_bios_z80_raw_decompiled.c | 952 | ProgramSoundChannelRegisters@ram:10b9 | 0x00 | UPPER8 | W | DYNAMIC | value expr: puVar3[-2]
pgm_bios_z80 | pgm_bios_z80_raw_decompiled.c | 954 | ProgramSoundChannelRegisters@ram:10b9 | 0x0d | UPPER8 | W | 0x03
pgm_bios_z80 | pgm_bios_z80_raw_decompiled.c | 956 | ProgramSoundChannelRegisters@ram:10b9 | 0x10 | UPPER8 | W | 0x00
pgm_bios_z80 | pgm_bios_z80_raw_decompiled.c | 1020 | ProgramSoundChannelMinimal@ram:1208 | 0x4f | LOWER8 | W | DYNAMIC | WriteICSSelectOscillator; value expr: puVar4[-4]
pgm_bios_z80 | pgm_bios_z80_raw_decompiled.c | 1024 | ProgramSoundChannelMinimal@ram:1208 | 0x01 | WORD | W | DYNAMIC | value expr: value
pgm_bios_z80 | pgm_bios_z80_raw_decompiled.c | 1043 | SetSoundChannelWaveIndex@ram:126e | 0x4f | LOWER8 | W | DYNAMIC | WriteICSSelectOscillator; value expr: voice_slot
pgm_bios_z80 | pgm_bios_z80_raw_decompiled.c | 1044 | SetSoundChannelWaveIndex@ram:126e | 0x09 | WORD | W | DYNAMIC | value expr: z80_wave_frequency_table[(byte)puVar1[-2]]
pgm_bios_z80 | pgm_bios_z80_raw_decompiled.c | 1065 | ConfigureSoundChipVoiceMode@ram:12bb | 0x43 | LOWER8 | R
pgm_bios_z80 | pgm_bios_z80_raw_decompiled.c | 1069 | ConfigureSoundChipVoiceMode@ram:12bb | 0x40 | LOWER8 | W | DYNAMIC | value expr: puVar3[-4]
pgm_bios_z80 | pgm_bios_z80_raw_decompiled.c | 1070 | ConfigureSoundChipVoiceMode@ram:12bb | 0x42 | LOWER8 | W | DYNAMIC | value expr: puVar3[-2]
pgm_bios_z80 | pgm_bios_z80_raw_decompiled.c | 1074 | ConfigureSoundChipVoiceMode@ram:12bb | 0x41 | LOWER8 | W | DYNAMIC | value expr: puVar3[-4]
pgm_bios_z80 | pgm_bios_z80_raw_decompiled.c | 1081 | ConfigureSoundChipVoiceMode@ram:12bb | 0x43 | LOWER8 | W | DYNAMIC | value expr: bVar2
pgm_bios_z80 | pgm_bios_z80_raw_decompiled.c | 1243 | HandleIrqBit0Service@ram:1519 | 0x43 | LOWER8 | R
pgm_bios_z80 | pgm_bios_z80_raw_decompiled.c | 1245 | HandleIrqBit0Service@ram:1519 | 0x41 | LOWER8 | R
pgm_bios_z80 | pgm_bios_z80_raw_decompiled.c | 1250 | HandleIrqBit0Service@ram:1519 | 0x40 | LOWER8 | R
pgm_bios_z80 | pgm_bios_z80_raw_decompiled.c | 1281 | HandleIrqBit1Service@ram:153b | 0x0f | UPPER8 | R
pgm_bios_z80 | pgm_bios_z80_raw_decompiled.c | 1292 | HandleIrqBit1Service@ram:153b | 0x4f | LOWER8 | W | DYNAMIC | WriteICSSelectOscillator; value expr: z80_irq_voice_index
pgm_bios_z80 | pgm_bios_z80_raw_decompiled.c | 1307 | HandleIrqBit1Service@ram:153b | 0x0d | UPPER8 | R
pgm_bios_z80 | pgm_bios_z80_raw_decompiled.c | 1330 | HandleIrqBit1Service@ram:153b | 0x00 | UPPER8 | R
pgm_bios_z80 | pgm_bios_z80_raw_decompiled.c | 1399 | InitializeSoundChipCore@ram:16a0 | 0x4c | LOWER8 | W | 0x03
pgm_bios_z80 | pgm_bios_z80_raw_decompiled.c | 1401 | InitializeSoundChipCore@ram:16a0 | 0x4d | LOWER8 | R
pgm_bios_z80 | pgm_bios_z80_raw_decompiled.c | 1403 | InitializeSoundChipCore@ram:16a0 | 0x4d | LOWER8 | W | DYNAMIC | value expr: bVar1 | 0xc
pgm_bios_z80 | pgm_bios_z80_raw_decompiled.c | 1405 | InitializeSoundChipCore@ram:16a0 | 0x4a | LOWER8 | W | 0x01
pgm_bios_z80 | pgm_bios_z80_raw_decompiled.c | 1481 | ResetSoundChipMixerState@ram:173b | 0x4d | LOWER8 | W | 0x00
pgm_bios_z80 | pgm_bios_z80_raw_decompiled.c | 1483 | ResetSoundChipMixerState@ram:173b | 0x4d | LOWER8 | R
pgm_bios_z80 | pgm_bios_z80_raw_decompiled.c | 1485 | ResetSoundChipMixerState@ram:173b | 0x4d | LOWER8 | W | 0x01
pgm_bios_z80 | pgm_bios_z80_raw_decompiled.c | 1543 | InitializeSoundChipVoicesAndTables@ram:17a6 | 0x4d | LOWER8 | R
pgm_bios_z80 | pgm_bios_z80_raw_decompiled.c | 1549 | InitializeSoundChipVoicesAndTables@ram:17a6 | 0x4d | LOWER8 | W | DYNAMIC | value expr: bVar4 & 0xf7
pgm_bios_z80 | pgm_bios_z80_raw_decompiled.c | 1551 | InitializeSoundChipVoicesAndTables@ram:17a6 | 0x0e | UPPER8 | W | 0x1f
pgm_bios_z80 | pgm_bios_z80_raw_decompiled.c | 1566 | InitializeSoundChipVoicesAndTables@ram:17a6 | 0x4f | LOWER8 | W | DYNAMIC | WriteICSSelectOscillator; value expr: (byte)uStack_6
pgm_bios_z80 | pgm_bios_z80_raw_decompiled.c | 1579 | InitializeSoundChipVoicesAndTables@ram:17a6 | 0x00 | UPPER8 | R
pgm_bios_z80 | pgm_bios_z80_raw_decompiled.c | 1586 | InitializeSoundChipVoicesAndTables@ram:17a6 | 0x0f | UPPER8 | R
pgm_bios_z80 | pgm_bios_z80_raw_decompiled.c | 1590 | InitializeSoundChipVoicesAndTables@ram:17a6 | 0x4f | LOWER8 | W | 0x00 | WriteICSSelectOscillator
pgm_bios_z80 | pgm_bios_z80_raw_decompiled.c | 1605 | InitializeSoundChipVoicesAndTables@ram:17a6 | 0x00 | UPPER8 | W | 0xa0
pgm_bios_z80 | pgm_bios_z80_raw_decompiled.c | 1607 | InitializeSoundChipVoicesAndTables@ram:17a6 | 0x4b | LOWER8 | R
pgm_bios_z80 | pgm_bios_z80_raw_decompiled.c | 1614 | InitializeSoundChipVoicesAndTables@ram:17a6 | 0x0e | UPPER8 | W | 0x1f
pgm_bios_z80 | pgm_bios_z80_raw_decompiled.c | 1616 | InitializeSoundChipVoicesAndTables@ram:17a6 | 0x00 | UPPER8 | W | 0x00
pgm_bios_z80 | pgm_bios_z80_raw_decompiled.c | 1618 | InitializeSoundChipVoicesAndTables@ram:17a6 | 0x0f | UPPER8 | R
pgm_bios_z80 | pgm_bios_z80_raw_decompiled.c | 1621 | InitializeSoundChipVoicesAndTables@ram:17a6 | 0x4d | LOWER8 | W | DYNAMIC | value expr: (byte)(uStack_6 >> 8)

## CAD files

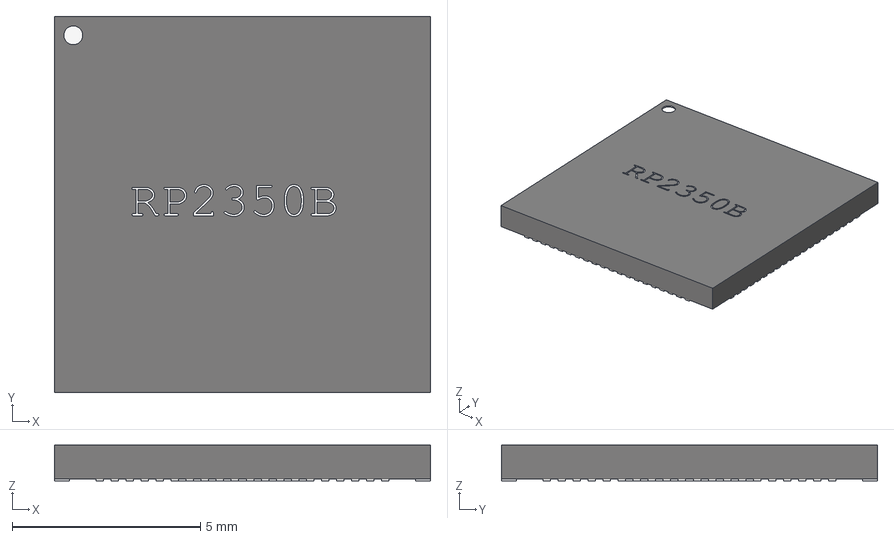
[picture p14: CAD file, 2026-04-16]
hardware/PGMPicoProg/RP2350_QFN80.step
10.0 x 10.0 x 0.95 mm

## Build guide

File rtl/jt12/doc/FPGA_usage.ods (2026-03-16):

 | FF | LUT
Acc | 86 | 82
EG | 174 | 267
MMR | 207 | 216
OP | 158 | 204
PG | 136 | 211
Other | 49 | 63
total | 810 | 1043

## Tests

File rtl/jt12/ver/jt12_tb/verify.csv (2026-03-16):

1 | 6 | 6 | 1a | 1 | 0b | 1 | 1e | 02 | b | 8 | 1 | 7
1 | 5 | 8 | 37 | 2 | 1b | 0 | 0a | 1b | 0 | 1 | 0 | 4
1 | 2 | d | 5a | 2 | 0e | 1 | 0f | 1b | e | 5 | 1 | 4
1 | 7 | 7 | 17 | 0 | 01 | 0 | 0c | 05 | c | 9 | 1 | 6
1 | 7 | 1 | 54 | 0 | 10 | 0 | 12 | 15 | 4 | a | 0 | 3
1 | 1 | 9 | 76 | 1 | 01 | 0 | 0c | 09 | 9 | 8 | 0 | 1
2 | 4 | 2 | 33 | 1 | 12 | 1 | 01 | 1a | e | 9 | 1 | 3
2 | 7 | c | 66 | 2 | 14 | 1 | 1c | 1a | e | b | 0 | 3
2 | 4 | b | 31 | 2 | 02 | 1 | 18 | 09 | a | f | 1 | 3
2 | 7 | 6 | 25 | 2 | 1d | 0 | 10 | 1c | 0 | 1 | 0 | 3
2 | 4 | f | 58 | 0 | 09 | 1 | 0f | 18 | 4 | b | 1 | 0
2 | 6 | d | 5a | 3 | 01 | 0 | 18 | 19 | 0 | 7 | 1 | 6
4 | 6 | b | 1f | 3 | 0d | 1 | 1e | 1e | f | f | 0 | 6
4 | 4 | 2 | 32 | 3 | 14 | 0 | 0b | 0a | f | 1 | 1 | 4
4 | 3 | 8 | 58 | 1 | 14 | 1 | 1c | 11 | 3 | 7 | 1 | 2
4 | 6 | 9 | 5d | 1 | 1c | 1 | 1b | 1c | c | a | 0 | 1
4 | 5 | a | 69 | 3 | 1e | 0 | 1c | 1e | 6 | b | 1 | 4
4 | 6 | a | 2e | 0 | 1c | 0 | 1b | 1c | 9 | 4 | 1 | 1
8 | 7 | 3 | 49 | 3 | 06 | 0 | 17 | 03 | b | 5 | 0 | 0
8 | 6 | 4 | 0d | 3 | 11 | 0 | 16 | 1a | 0 | 3 | 0 | 5
8 | 2 | 7 | 23 | 0 | 01 | 0 | 0a | 06 | e | 0 | 0 | 5
8 | 4 | 3 | 05 | 1 | 07 | 0 | 1b | 14 | d | 5 | 0 | 3
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

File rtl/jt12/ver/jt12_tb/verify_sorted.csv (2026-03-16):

1 | 1 | 9 | 76 | 1 | 01 | 0 | 0c | 09 | 9 | 8 | 0 | 1
1 | 2 | d | 5a | 2 | 0e | 1 | 0f | 1b | e | 5 | 1 | 4
1 | 5 | 8 | 37 | 2 | 1b | 0 | 0a | 1b | 0 | 1 | 0 | 4
1 | 6 | 6 | 1a | 1 | 0b | 1 | 1e | 02 | b | 8 | 1 | 7
1 | 7 | 1 | 54 | 0 | 10 | 0 | 12 | 15 | 4 | a | 0 | 3
1 | 7 | 7 | 17 | 0 | 01 | 0 | 0c | 05 | c | 9 | 1 | 6
2 | 4 | 2 | 33 | 1 | 12 | 1 | 01 | 1a | e | 9 | 1 | 3
2 | 4 | b | 31 | 2 | 02 | 1 | 18 | 09 | a | f | 1 | 3
2 | 4 | f | 58 | 0 | 09 | 1 | 0f | 18 | 4 | b | 1 | 0
2 | 6 | d | 5a | 3 | 01 | 0 | 18 | 19 | 0 | 7 | 1 | 6
2 | 7 | 6 | 25 | 2 | 1d | 0 | 10 | 1c | 0 | 1 | 0 | 3
2 | 7 | c | 66 | 2 | 14 | 1 | 1c | 1a | e | b | 0 | 3
4 | 3 | 8 | 58 | 1 | 14 | 1 | 1c | 11 | 3 | 7 | 1 | 2
4 | 4 | 2 | 32 | 3 | 14 | 0 | 0b | 0a | f | 1 | 1 | 4
4 | 5 | a | 69 | 3 | 1e | 0 | 1c | 1e | 6 | b | 1 | 4
4 | 6 | 9 | 5d | 1 | 1c | 1 | 1b | 1c | c | a | 0 | 1
4 | 6 | a | 2e | 0 | 1c | 0 | 1b | 1c | 9 | 4 | 1 | 1
4 | 6 | b | 1f | 3 | 0d | 1 | 1e | 1e | f | f | 0 | 6
8 | 0 | b | 63 | 2 | 07 | 1 | 1c | 1b | a | d | 1 | 4
8 | 2 | 7 | 23 | 0 | 01 | 0 | 0a | 06 | e | 0 | 0 | 5
8 | 4 | 3 | 05 | 1 | 07 | 0 | 1b | 14 | d | 5 | 0 | 3
8 | 6 | 4 | 0d | 3 | 11 | 0 | 16 | 1a | 0 | 3 | 0 | 5
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

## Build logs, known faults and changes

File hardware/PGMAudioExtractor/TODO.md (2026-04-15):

# TODO

## Remaining work

- review whether block timestamps are sufficient or whether dedicated anchor packets would improve reconstruction
- investigate the reported `stream_dropped_packets` status counter and decide whether it reflects only startup/no-host drops or an avoidable steady-state condition
- consider adding a separate debug/control channel if simultaneous human-readable logging is needed
- add optional host-side tools for splitting captures by detected rate changes or exporting alternative metadata formats
- decide whether the shared `ring_buffer` helper should stay or be simplified now that UAC is gone

## Nice to have

- richer post-capture analysis and summary tooling
- optional FLAC export on the host side
- host-to-device control commands for future capture modes

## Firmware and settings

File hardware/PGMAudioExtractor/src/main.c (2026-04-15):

#include "bsp/board_api.h"
#include "pico/stdlib.h"
#include "pico/time.h"
#include "rate_measure.h"
#include "serial_audio_capture.h"
#include "capture_stream.h"
#include "tusb.h"

static void led_task(void) {
    static uint32_t last_toggle_ms;
    static bool led_state;

    uint32_t interval_ms = 250;
    if (tud_suspended()) {
        interval_ms = 2000;
    } else if (tud_mounted()) {
        interval_ms = 1000;
    }

    uint32_t now = board_millis();
    if ((now - last_toggle_ms) >= interval_ms) {
        last_toggle_ms = now;
        led_state = !led_state;
        board_led_write(led_state);
    }
}

static uint32_t build_capture_flags(void) {
    uint32_t flags = 0;
    if (rate_measure_is_valid()) {
        flags |= PGM_CAPTURE_FLAG_RATE_VALID;
    }
    if (serial_audio_capture_is_running()) {
        flags |= PGM_CAPTURE_FLAG_CAPTURE_RUNNING;
    }
    if (serial_audio_capture_get_dropped_dma_blocks() != 0u) {
        flags |= PGM_CAPTURE_FLAG_DMA_DROP;
    }
    if (serial_audio_capture_get_dropped_audio_frames() != 0u) {
        flags |= PGM_CAPTURE_FLAG_AUDIO_DROP;
    }
    if (capture_stream_get_dropped_packets() != 0u) {
        flags |= PGM_CAPTURE_FLAG_QUEUE_DROP;
    }
    if (!capture_stream_connected()) {
        flags |= PGM_CAPTURE_FLAG_NO_HOST;
    }
    return flags;
}

static void status_task(void) {
    static uint32_t last_status_ms;

    uint32_t now_ms = board_millis();
    if ((now_ms - last_status_ms) < 1000u) {
        return;
    }
    last_status_ms = now_ms;

    pgm_capture_status_payload_t status = {
        .uptime_ms = now_ms,
        .rate_hz = rate_measure_get_hz(),
        .raw_rate_hz = rate_measure_get_raw_hz(),
        .edge_count = rate_measure_get_edge_count(),
        .elapsed_us = rate_measure_get_elapsed_us(),
        .idle_us = rate_measure_get_idle_us(),
        .rate_status = (uint32_t)rate_measure_get_status(),
        .ready_mask = serial_audio_capture_get_ready_mask(),
        .processed_dma_blocks = serial_audio_capture_get_processed_dma_blocks(),
        .dropped_dma_blocks = serial_audio_capture_get_dropped_dma_blocks(),
        .dropped_audio_frames = serial_audio_capture_get_dropped_audio_frames(),
        .channel_word_count = serial_audio_capture_get_channel_word_count(),
        .stereo_frame_count = serial_audio_capture_get_stereo_frame_count(),
        .nonzero_sample_count = serial_audio_capture_get_nonzero_sample_count(),
        .last_left_sample = serial_audio_capture_get_last_left_sample(),
        .last_right_sample = serial_audio_capture_get_last_right_sample(),
        .stream_dropped_packets = capture_stream_get_dropped_packets(),
        .stream_dropped_bytes = capture_stream_get_dropped_bytes(),
        .stream_queue_depth = capture_stream_get_queue_depth(),
        .reserved = 0,
    };

    capture_stream_submit_status(time_us_64(), build_capture_flags(), &status);
}

int main(void) {
    board_init();

    serial_audio_capture_config_t capture_config = {
        .si_gpio = 13,
        .clk_gpio = 14,
        .lrclk_gpio = 15,
        .lrclk_low_is_left = true,
        .sample_on_rising_edge = true,
        .bits_per_sample = 16,
    };

    rate_measure_init(capture_config.lrclk_gpio);
    capture_stream_init();
    serial_audio_capture_init(&capture_config);

    tusb_rhport_init_t dev_init = {
        .role = TUSB_ROLE_DEVICE,
        .speed = TUSB_SPEED_AUTO,
    };
    tusb_init(BOARD_TUD_RHPORT, &dev_init);

    if (board_init_after_tusb) {
        board_init_after_tusb();
    }

    rate_measure_enable();
    serial_audio_capture_enable();

    while (true) {
        tud_task();
        rate_measure_task();
        serial_audio_capture_task();
        status_task();
        capture_stream_task();
        led_task();
    }

    return 0;
}

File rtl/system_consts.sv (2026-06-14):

package system_consts;
    parameter int SSIDX_GLOBAL = 0;
    parameter int SSIDX_WORK_RAM = 1;
    parameter int SSIDX_VIDEO_RAM = 2;
    parameter int SSIDX_PAL_RAM = 3;
    parameter int SSIDX_IGS023 = 4;
    parameter int SSIDX_Z80_RAM = 5;
    parameter int SSIDX_Z80 = 6;
    parameter int SSIDX_IGS026_X = 7;
    parameter int SSIDX_ICS2115 = 8;
    parameter int SSIDX_ASIC3 = 9;
    parameter int SSIDX_IGS025 = 10;
    parameter int SSIDX_IGS022 = 11;          // engine regs[]/stack[]/stack_ptr
    parameter int SSIDX_IGS022_RAM_LO = 12;   // shared protection RAM, low bytes
    parameter int SSIDX_IGS022_RAM_HI = 13;   // shared protection RAM, high bytes
    parameter int SSIDX_IGS027A       = 14;   // ARM7 core (64 words) + igs027a wrapper regs
    parameter int SSIDX_IGS027A_IRAM  = 15;   // internal RAM (up to 256KB) via ram_cache rd/wr ports
    parameter int SSIDX_IGS027A_SHARE = 16;   // 68k/ARM shared RAM (64KB)
    parameter int SSIDX_IGS027A_XOR   = 17;   // exrom XOR table (1KB)

    parameter bit [31:0] SS_DDR_BASE         = 32'h3E00_0000;
    // Free DDR window (was the sprite A-ROM, now moved to SDRAM).
    parameter bit [31:0] CART_A_ROM_DDR_BASE = 32'h3800_0000;
    parameter bit [31:0] DOWNLOAD_DDR_BASE   = 32'h3000_0000;
    parameter bit [31:0] CART_ARM_ROM_DDR_BASE = 32'h3C00_0000;
    parameter bit [31:0] PROT_INT_ROM_DDR_BASE = 32'h3C90_0000; // igs027a 16KB internal ROM
    parameter bit [31:0] PROT_IRAM_DDR_BASE    = 32'h3CA0_0000; // igs027a internal RAM, up to 256KB (P2)
    parameter bit [31:0] PROT_ROM_DDR_BASE     = 32'h3CB0_0000; // igs022 64KB private data ROM
    // IGS027A 68k/ARM shared RAM, two 64KB "chips" (was 128KB block RAM).  chip0
    // @ base, chip1 @ base+0x10000.  Fronted by one ram_cache per chip.
    parameter bit [31:0] PROT_SHARE_DDR_BASE   = 32'h3CC0_0000; // 2x 64KB shared RAM chips

    /*
    SDRAM map (128 MB, 2x 64 MB chips; chip = addr[26]).  Latency-sensitive
    graphics (tiles + sprite B + sprite A) live in SDRAM; A fills chip 1.

    chip 0 (0x0000_0000-0x03FF_FFFF):
      BIOS  PROG  1M  @ 0x0000_0000
      BIOS  TILE  2M  @ 0x0010_0000
      BIOS  MUSIC 2M  @ 0x0030_0000
      CART  PROG  8M  @ 0x0080_0000
      CART  TILE 16M  @ 0x0100_0000
      CART  MUSIC 16M @ 0x0200_0000
      CART  B    16M  @ 0x0300_0000
    chip 1 (0x0400_0000-0x07FF_FFFF):
      CART  A    64M  @ 0x0400_0000
    */

    parameter bit [31:0] BIOS_PROG_ROM_SDR_BASE   = 32'h0000_0000;
    parameter bit [31:0] BIOS_TILE_ROM_SDR_BASE   = 32'h0010_0000;
    parameter bit [31:0] BIOS_MUSIC_ROM_SDR_BASE  = 32'h0030_0000;

    parameter bit [31:0] CART_PROG_ROM_SDR_BASE   = 32'h0080_0000;
    parameter bit [31:0] CART_TILE_ROM_SDR_BASE   = 32'h0100_0000;
    parameter bit [31:0] CART_MUSIC_ROM_SDR_BASE  = 32'h0200_0000;
    parameter bit [31:0] CART_B_ROM_SDR_BASE      = 32'h0300_0000;
    parameter bit [31:0] CART_A_ROM_SDR_BASE      = 32'h0400_0000;

    typedef enum bit [3:0] {
        STORAGE_SDR,
        STORAGE_DDR,
        STORAGE_BLOCK
    } region_storage_t;

    typedef enum bit [3:0] {
        ENCODING_NORMAL,
        ENCODING_SWAP16,
        ENCODING_ENCRYPTED
    } region_encoding_t;

    typedef struct packed {
        bit [31:0] base_addr;
        region_storage_t storage;
        region_encoding_t encoding;
        bit [3:0]  base_idx;
    } region_t;
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

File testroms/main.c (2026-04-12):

#include <stdint.h>
#include <stdbool.h>

#include "interrupts.h"
#include "tilemap.h"
#include "input.h"
#include "system.h"
#include "page.h"
#include "memory_map.h"
#include "igs023.h"

#include "util.h"

#include "color.h"

__attribute__ ((section(".sprite_buffer"))) __attribute__((used))
IGS023Sprite SPRITE_BUFFER[256];

void level6_handler()
{
    if( !page_irq6() )
        igs023_ack_irq6();
}

void level4_handler()
{
    if( !page_irq4() )
        igs023_ack_irq4();
}

void illegal_instruction_handler()
{
    disable_interrupts();

    text_color(1);
    text_at(10,10,"ILLEGAL INSTRUCTION");

    while(true) {};
}

int main(int argc, char *argv[])
{
    igs023_init();

    memset(SPRITE_BUFFER, 0, 256 * 10);
    
    input_init();

    input_update();

    page_set_next_active();

    while(1)
    {
        input_update();

        if (input_pressed(START))
        {
            page_set_next_active();
        }

        page_update();
    }

    return 0;
}

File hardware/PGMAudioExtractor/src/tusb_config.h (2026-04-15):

#ifndef _TUSB_CONFIG_H_
#define _TUSB_CONFIG_H_

#ifdef __cplusplus
extern "C" {
#endif

#include "usb_descriptors.h"

#ifndef BOARD_TUD_RHPORT
#define BOARD_TUD_RHPORT 0
#endif

#ifndef BOARD_TUD_MAX_SPEED
#define BOARD_TUD_MAX_SPEED OPT_MODE_DEFAULT_SPEED
#endif

#ifndef CFG_TUSB_MCU
#error CFG_TUSB_MCU must be defined
#endif

#ifndef CFG_TUSB_OS
#define CFG_TUSB_OS OPT_OS_NONE
#endif

#ifndef CFG_TUSB_DEBUG
#define CFG_TUSB_DEBUG 0
#endif

#define CFG_TUD_ENABLED 1
#define CFG_TUD_MAX_SPEED BOARD_TUD_MAX_SPEED

#ifndef CFG_TUSB_MEM_SECTION
#define CFG_TUSB_MEM_SECTION
#endif

#ifndef CFG_TUSB_MEM_ALIGN
#define CFG_TUSB_MEM_ALIGN __attribute__((aligned(4)))
#endif

#ifndef CFG_TUD_ENDPOINT0_SIZE
#define CFG_TUD_ENDPOINT0_SIZE 64
#endif

#define CFG_TUD_AUDIO 0
#define CFG_TUD_CDC 1
#define CFG_TUD_MSC 0
#define CFG_TUD_HID 0
#define CFG_TUD_MIDI 0
#define CFG_TUD_VENDOR 0

#define CFG_TUD_CDC_RX_BUFSIZE 512
#define CFG_TUD_CDC_TX_BUFSIZE 512
#define CFG_TUD_CDC_EP_BUFSIZE 64

#ifdef __cplusplus
}
#endif

#endif

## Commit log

2026-03-16 Initial commit Based on F2 core
    [FPGA_usage.ods, algorithm.ods, arduino.kicad_pcb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]
2026-03-16 Switch IGS023 to 50Mhz clock and generate 10Mhz pixel clock internally
2026-03-22 Fixed DE-10 compilation
    Switch system clock to 50Mhz, SDRAM to 100Mhz
2026-03-22 Use correct tile rom when reading fg rom
    [igs023.sv]
2026-03-25 Hardware files for PGM Pico Prog and Passthrough Gartridge Module
    [PGMPassThru.kicad_pcb, PGMPassThru.kicad_sch, PGMPicoProg.kicad_pcb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]
2026-03-27 Add v3021 RTC timer and the beginnings of the Z80 related IGS026
2026-03-31 Flip audio endian. Fix SDR width
    [PGM.sv]
2026-04-11 Added additional test rom pages Fix save state support
    [PGM.sv, igs023.sv, main.c]
2026-04-12 Added test for irq4 performance. Confirmed timer continues to increment when irq is disabled. Updated core to match
2026-04-12 fix(pgmaudioextractor): use sdk usb reset interface
    [main.c]
2026-04-14 fix(usb-audio): prevent ep panic on stream reopen
    Clear EP1 IN buffer control register in close callback to prevent
    USB_BUF_CTRL_AVAIL persisting across ISO endpoint reactivation on
    RP2040/RP2350. Also fix serial descriptor, add audio lifecycle
    instrumentation, and add reconnect-aware serial monitor tool.
    [main.c]
2026-04-14 fix(rate): default USB sample rate to source clock
    Default the nominal capture rate to 33074 Hz and snap runtime
    measurement to the known 33074/44100 Hz source rates.
    Also update TODO.md to reflect the current MVP state and the
    remaining validation and cleanup work.
2026-04-15 feat(capture): stream timestamped audio blocks over cdc
    Replace the UAC capture path with a native-rate CDC extractor that
    sends binary packets containing PCM frames, frame indices, block
    sequence numbers, timestamps, and measured LRCLK metadata.
    Add a Python receiver that records WAV output plus JSONL metadata,
    and keep the firmware resilient when no source data is present or no
    host is connected and reading.
    [main.c, tusb_config.h]
2026-04-15 refactor(capture): document and harden cdc extractor
    Document the native-rate CDC packet protocol, improve the host
    receiver with summary and gap reporting, remove the obsolete UAC
    implementation, and unify packet sequencing across audio and status
    packets.
    A 30-second strict capture check completed with zero packet and frame
    gaps on macOS.
2026-04-16 Git ignore cleanup
    [RP2350_QFN80.step]
2026-04-18 Enable video signals during reset
    [igs023.sv]
2026-04-20 Changed vram and palram to match hardware.
    Working IGS023 FG line buffer implementation. Some glitches to work out.
    [PGM.sv, igs023.sv]
2026-05-04 ICS interrupt fixes
2026-05-05 Tilemap improvements
    Give BG more time to preread rom dats
    Ensure the SDRAM req/ack is reset when switching back to FG rom reading
    [igs023.sv]
2026-05-09 Fix for sprites the wrap around their y-coordinate and added sprite debugging UI
    [igs023.sv, igs023_sprite.sv]
2026-05-19 Audio fixes
    Correct ICS2115 sample format selection
    Fix interpolation and sign extension
    Add test framework
2026-06-12 Old audio tests and sim save state fix
    [PGM.sv]
2026-06-12 First pass for ICS2115 validation
    [ics2115_access_inventory.csv]
2026-06-13 Add horizontal scaler for consumer CRT width correction
    New video_hscale module re-emits each line at the full 50MHz clock (5x
    the native 10MHz pixel rate) so the active width can be scaled in 1.25%
    steps (80%..118.75%) without visible aliasing on analog output. Hsync
    is regenerated with an auto-centering shift plus a user offset control;
    parameters latch at vblank. Line buffer is a single 128x24 BRAM.
    - Hooked into video_path ahead of video_mixer; forces the scandoubler
    off while enabled (output is already one pixel per clock)
    - OSD: H-Scaler enable (status[20]), H-Scale (status[25:21]),
    H-Scale Pos (status[30:26]) in the analog video section
    - Sim: scaler instantiated in sim_top behin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
    [sim_controller.h]
2026-06-13 Remove H-scaler from sim pipeline
    Scaler is verified working on FPGA, so it no longer needs to live in
    the Verilator build. Restore the sim-side files to their pre-scaler
    state (sim_top, build lists, sim_video, controller, protocol, docs)
    and drop the verification scripts. The scaler RTL and its FPGA-path
    integration (video_path, Arcade-IGSPGM, files.qip, mister.f) are
    unchanged.
    [sim_controller.h]
2026-06-14 Fix sprite X scaling and handle 0-sized sprites
    Fixes kov2 card
    Fixes theglad sprite artifact
    [igs023_sprite.sv]
2026-06-14 Release 20260613
    Improved ICS2115 accuracy
    Fixed sprite scaling and 0-height sprites
    Added H-scaler
    Fixed ARM type3 savestates
    [igs023_buffer.sv, system_consts.sv]
2026-06-14 Fix missing first column of off screen sprites
    [igs023_buffer.sv]
2026-06-16 Fix timer IRQ clearing
